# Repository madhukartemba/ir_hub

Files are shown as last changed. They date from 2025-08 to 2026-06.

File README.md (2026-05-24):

# IR Hub

A self-contained, open-source smart IR universal remote built around the ESP8266. IR Hub learns the codes from your existing TV/AC/audio remotes, stores them locally, and lets you fire them from a physical button, an on-device menu, Home Assistant (MQTT), or Alexa — all over your home Wi-Fi.

It ships as a complete hardware + firmware project: custom KiCad PCB, 3D-printed enclosure, and PlatformIO firmware with OTA updates.

- **Help (web preview):** https://ir-hub.pages.dev/help
- **Help (markdown source):** [`docs/HELP.md`](docs/HELP.md)
- **Release / OTA notes:** [`docs/RELEASE.md`](docs/RELEASE.md)

---

## What It Does

- **Learns IR remotes.** Point any IR remote at the receiver, press a button, and the Hub stores the raw signal.
- **Replays IR commands.** 8x parallel high-current IR LEDs give very long range so the Hub can sit across the room from the appliance.
- **Smart home bridge.** Each learned device shows up as an MQTT entity (works great with Home Assistant) and as an Alexa-controllable device (via Espalexa).
- **Standalone UI.** 128x64 OLED + single button + 30-LED NeoPixel ring + haptic motor + buzzer. No phone required for day-to-day use.
- **Captive-portal Wi-Fi setup.** First boot exposes an `IRHub V3 Setup` AP; users join it and configure Wi-Fi + MQTT from their phone.
- **OTA updates.** Cloud OTA (via Cloudflare Pages manifest, polled hourly) and LAN OTA (ArduinoOTA + mDNS auto-discovery).
- **Safe boot.** Boot-loop counter + LittleFS format-on-failure recovery so a bad save never bricks the device.

---

## Hardware Variants

**Only `v3` (the custom PCB build) is actively supported.** The older `v0` (NodeMCU perfboard) and `v1` (D1 Mini perfboard) variants still exist in the codebase as historical prototypes, but they are **deprecated** — no longer maintained, no longer released, and not recommended for new builds.

The rest of this README only covers v3.

---

## Bill of Materials (v3)

Full BOM with LCSC-style designators lives in [`PCB/IRHub_PCB_V3/production/bom.csv`](PCB/IRHub_PCB_V3/production/bom.csv). The major active parts:

| Block | Part | Role |
|---|---|---|
| MCU | **ESP-12F** (ESP8266) | Brains + Wi-Fi |
| USB | **USB-C receptacle + CH340C** | USB-UART for programming and 5 V power |
| Power | **AMS1117-3.3** LDO | 5 V -> 3.3 V regulation |
| Display | **OLED-128O064D** (SH1106, I²C) | 128x64 status/menu screen |
| LEDs | **30x WS2812B-2020** | Circular addressable RGB ring |
| IR TX | **8x IR204A** + UMH3N driver + AO3400A MOSFET | High-current IR blaster array |
| IR RX | **TSOP382xx** | 38 kHz IR demodulator for learning |
| Haptics | **DRV2605L** + external LRA (JST connector) | Tactile click feedback |
| Audio | **CMT-7525-80-SMT-TR** magnetic buzzer | UI beeps / chimes |
| Input | **Single tactile push button** | All UI navigation |

Plus passives, test points, and the JST-SH connector for the LRA.

---

## How To Build One (v3)

### 1. Order the PCB

KiCad project: [`PCB/IRHub_PCB_V3/`](PCB/IRHub_PCB_V3/)

- Source schematic + board: `IRHub_V3.kicad_sch`, `IRHub_V3.kicad_pcb`
- Manufacturing bundle: [`PCB/IRHub_PCB_V3/production/IR_Hub_3.zip`](PCB/IRHub_PCB_V3/production/IR_Hub_3.zip) (gerbers + drills, ready to upload to JLCPCB / PCBWay / OSHPark)
- For JLCPCB-style PCBA also use: `production/bom.csv` + `production/positions.csv`
- 3D preview / STEP: `IRHub_V3.step` and `IRHub_V3_Model.step`

Default board specs are 2-layer, 1.6 mm, HASL — anything in that ballpark from any low-cost fab works fine.

### 2. Print the Enclosure

3D-printable enclosure parts for the v3 PCB live in [`3D Print/Version 3/`](3D%20Print/Version%203/):

- `Base.stl` — main housing the PCB drops into
- `Top Cover.stl` — top shell with the OLED + button cutouts
- `Led Ring.stl` — diffuser ring that sits over the WS2812 ring

Plus the full Fusion 360 source as `IR Hub V3 v74.f3z`, and ready-to-print GCode under `3D Print/Version 3/GCode/`.

Recommended print settings: PLA, 0.2 mm layer height, 15–20% infill, supports off for `Top Cover` (geometry is overhang-friendly).

### 3. Assemble

1. Solder the PCB (or order PCBA). If hand-soldering, start with the QFP / SMD parts (CH340C, AMS1117, DRV2605L), then passives, then through-hole IR LEDs and the button, then the WS2812 ring last so it doesn't get cooked.
2. Verify 3.3 V on test point `TP9` and 5 V on `5V1` *before* installing the ESP-12F.
3. Solder/clip in the OLED, plug the LRA into the JST-SH connector.
4. Drop the populated PCB into the printed `Base`, screw on `Top Cover`, slip `Led Ring` over the LEDs.

### 4. Flash the Firmware

You only need to do this once — after that, OTA updates take over.

1. Install **PlatformIO** (VS Code extension or `pip install platformio`).
2. Clone this repo and open it in PlatformIO.
   ```bash
   git clone https://github.com/madhukartemba/ir_hub.git
   cd ir_hub
   ```
3. Create your `include/secrets.h` from the template:
   ```bash
   cp include/secrets.h.example include/secrets.h
   ```
   Edit it to set (all optional, but recommended):
   - `MQTT_HOST` / `MQTT_USER` / `MQTT_PASSWORD` — Home Assistant broker.
   - `OTA_PASSWORD` — required for LAN OTA pushes.
   - `OTA_MANIFEST_URL` — your Cloudflare Pages manifest URL (only needed if you fork and self-host releases).
4. Plug the assembled board into USB-C and run:
   ```bash
   pio run -e ir_hub_version_3 -t upload
   ```
5. Open the serial monitor to see boot logs:
   ```bash
   pio device monitor -b 115200
   ```

That's it — the rest of the configuration (Wi-Fi, MQTT credentials, learned remotes) happens on-device.

### 5. Power On & Configure

On first boot the Hub shows `IR Hub — Ready! (Offline)` and starts a captive-portal AP called **`IRHub V3 Setup`**. Connect a phone to it and the captive portal walks you through Wi-Fi (and optional MQTT) setup. From there, see the [User Help Guide](docs/HELP.md) for adding remotes, using Alexa, etc.

---

## Pinout (v3)

For reference, defined in [`src/config.h`](src/config.h):

| Function | ESP-12F Pin |
|---|---|
| Button | D0 |
| OLED SCL | D1 |
| OLED SDA | D2 |
| Buzzer | D3 |
| IR Receiver | D5 |
| IR Transmitter | D6 |
| NeoPixel ring | D7 |

---

## Project Layout

```
ir_hub/
  src/                Firmware entry + UI screens
  lib/                Internal libraries (IR, MQTT, Display, OtaUpdater, etc.)
  include/            Project headers + secrets template
  PCB/                KiCad sources + gerbers + production BOM (v3; v1 archived)
  3D Print/           Fusion sources + STL + GCode for enclosures
  docs/               User help, release/OTA documentation
  scripts/            Release automation + local OTA upload helper
  ota/                Public OTA manifest served via Cloudflare Pages
  binaries/           Signed firmware images served via Cloudflare Pages
```

---

## For Developers

All commands target v3 — the older `v0` / `v1` PlatformIO envs are deprecated and not part of the release pipeline.

- **Build:** `pio run -e ir_hub_version_3`
- **Cut a release:** `python3 scripts/release.py 1.2.3` — bumps `custom_firmware_version`, builds `ir_hub_version_3`, stages the binary under `binaries/`, updates `ota/manifest.json`, commits + pushes. See [`docs/RELEASE.md`](docs/RELEASE.md) for the full flow.
- **LAN OTA push:** `python3 scripts/local_upload_ota.py -e ir_hub_version_3 --discover` — mDNS-discovers `ir-hub-*` devices and pushes the current build over the network. Password is read from `include/secrets.h`.

---

## License

MIT — see `LICENSE` (or use the source freely; attribution appreciated).

---

<div align="center">
  Made by <a href="mailto:madhusmiles.madhukar@gmail.com">Madhukar Temba</a>
</div>

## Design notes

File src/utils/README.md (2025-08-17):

# Utils Directory

This directory contains utility classes and functions that can be reused across different parts of the application.

## MenuUtils

The `MenuUtils` class provides a reusable scrollable menu implementation that can be used across different screens in the application.

### Features

- **Scrollable Menus**: Automatically handles scrolling when there are more menu items than can fit on screen
- **Multiple Input Types**: Supports different input formats (vector of strings, array of const char\*, etc.)
- **Consistent UI**: Provides a consistent look and feel across all menus
- **Easy Integration**: Simple to integrate into existing screens

### Usage

```cpp
#include "../utils/MenuUtils.h"

// For const char* arrays
const char* menuItems[] = {"Option 1", "Option 2", "Option 3", "Back"};
MenuUtils::drawScrollableMenu(menuItems, 4, selectedIndex, 3, 20);

// For vector of strings
std::vector<std::string> items = {"Option 1", "Option 2", "Option 3"};
MenuUtils::drawScrollableMenu(items, selectedIndex, 3, 20);
```

### Parameters

- `items`: Array or vector of menu items
- `selectedIndex`: Currently selected item index
- `maxVisibleItems`: Maximum number of items to show at once (default: 3)
- `startY`: Y-coordinate to start drawing the menu (default: 20)

### Integration

To use this utility in a new screen:

1. Include the header: `#include "../utils/MenuUtils.h"`
2. Add a `selectedIndex` member variable to track selection
3. Update the button click handler to increment `selectedIndex`
4. Replace manual menu drawing with `MenuUtils::drawScrollableMenu()`

### Examples

See the following files for examples of how to use MenuUtils:

- `src/ui/settings/Settings.h`
- `src/ui/devices/Devices.h`
- `src/ui/devices/DeviceActions.h`
- `src/ui/MainMenu.h`

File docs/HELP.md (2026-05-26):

# IR Hub — User Guide

Welcome to your IR Hub! This guide walks you through everything you need — setting it up, using it daily, and getting the most out of its smart-home features.

> Looking for something specific? Jump straight to the section you need below.

## Quick Navigation

- [What is IR Hub?](#what-is-ir-hub)
- [Button Cheat Sheet](#button-cheat-sheet)
- [LED Ring Colors](#led-ring-colors)
- [First-Time Setup](#first-time-setup)
- [Adding a Remote (Add Device)](#adding-a-remote-add-device)
- [Using Your Saved Devices](#using-your-saved-devices)
- [Smart Home Integration](#smart-home-integration)
- [Settings Menu](#settings-menu)
- [Keeping It Up to Date](#keeping-it-up-to-date)
- [Upgrading to 2.0.0](#upgrading-to-200)
- [Resetting Your Hub](#resetting-your-hub)
- [Troubleshooting](#troubleshooting)
- [Contact & Support](#contact--support)

---

## What is IR Hub?

IR Hub is a smart infrared (IR) remote that lives in one place in your home and replaces a drawer full of remotes. It can:

- **Learn** the button presses from any IR remote you already own (TV, AC, set-top box, fan, soundbar — anything that uses an IR remote).
- **Replay** those signals on command, with enough range to reach across the room.
- **Connect to your smart home** so you can also trigger your appliances from Home Assistant or Alexa.

Once set up, you can keep using your old remotes *and* control everything from your phone, your voice, or the Hub itself.

---

## Button Cheat Sheet

Everything on IR Hub is done with one button. Here's the full list of gestures:

| Where you are | Single Click | Long Press |
|---|---|---|
| Home screen (display sleeping) | Wake the screen | Wake the screen |
| Home screen (display awake) | (nothing) | Open the **Main Menu** |
| Inside a menu | Move to the **next item** | **Select** the highlighted item |
| Inside a confirmation screen | Cancel / go back | **Confirm** the action |

*Tip: If the screen is dark, just click once — that always wakes it up.*

---

## LED Ring Colors

The ring of lights around the Hub gives you quick visual feedback:

| Color | What it means |
|---|---|
| Soft white / breathing | Idle, ready to use |
| Green pulse | Sent a successful "ON" command |
| Orange / red pulse | Sent an "OFF" command |
| Rainbow sweep | Successfully added a new device |
| Solid green | Everything is connected and ready |
| Solid red | Something went wrong (check the screen for details) |
| Blue breathing | Currently looking at info screens or Help / Contact |

The ring will fade out after a few seconds of inactivity to save power — that's normal.

---

## First-Time Setup

When you first power your Hub on, here's what to expect:

1. **Plug it in.** The screen will say `IR Hub — Initializing...`, then the ring will light up.
2. **Connect to the setup network.** Take your phone and look for a Wi-Fi network named **`IRHub V3 Setup`**. Join it.
3. **Open the setup page.** Your phone may open the setup page automatically. If it doesn't, open **`http://192.168.4.1`** in your browser.
4. **Pick your Wi-Fi.** Choose your home Wi-Fi network from the list and enter the password.
5. *(Optional)* **Enter your MQTT details** if you want to connect to Home Assistant — see [Smart Home Integration](#smart-home-integration) below.
6. **Done!** The Hub will reboot, connect to your network, and show `Ready!` on the screen.

You can now start adding your remotes.

---

## Adding a Remote (Add Device)

Let's teach the Hub how to control one of your appliances.

1. From the Home screen, **long-press** the button to open the **Main Menu**.
2. Click to highlight **Add Device**, then long-press to select.
3. Grab the original remote for the appliance you want to control (e.g. your TV remote).
4. **Point the remote at the front of the Hub** (the small dark window is the IR receiver) from about 10–30 cm away.
5. When prompted, press the **ON** button on your remote.
6. When prompted again, press the **OFF** button (or repeat the same button if the appliance uses a single toggle).
7. The Hub will confirm with a rainbow sweep and a happy chime — your new device is saved!

**Recording tips:**
- Press firmly but briefly — a quick, deliberate press works better than holding it down.
- Make sure you have line-of-sight between your remote and the Hub.
- If recording fails, try again from a slightly closer distance.
- Avoid direct sunlight or bright halogen lights pointed at the Hub — they create IR noise.

---

## Using Your Saved Devices

Once you've added a device, you have three ways to control it:

**1. From the Hub itself**
- Open **Main Menu -> Devices**
- Pick the appliance and toggle it on/off

**2. From your phone / Home Assistant** (if MQTT is set up)
- Each device appears automatically as a switch in Home Assistant
- Trigger it from dashboards, automations, scripts, etc.

**3. With your voice** (Alexa, via local discovery)
- Say *"Alexa, discover devices"* once after adding a new appliance on the Hub
- Then use the name Alexa shows (you can rename it in the Alexa app for easier voice commands)
- The Hub supports up to **20** saved devices

---

## Smart Home Integration

### Home Assistant (MQTT)

If you have a Home Assistant install with an MQTT broker (e.g. Mosquitto), the Hub can connect to it automatically:

- During first-time setup, enter your **MQTT broker address**, **username**, and **password** in the captive portal.
- Each device you add later will publish itself on MQTT automatically — no Home Assistant config edits required.
- You can check the connection status at any time under **Settings -> MQTT status**.

### Alexa

The Hub exposes each saved device to Alexa over your local Wi-Fi (no Alexa skill or cloud account linking required):

1. Make sure your Echo and the Hub are on the **same Wi-Fi network** (same band — many routers split 2.4 GHz and 5 GHz).
2. Add at least one device on the Hub.
3. Say *"Alexa, discover devices"* — each appliance should appear as its own entry.
4. Control it by name, e.g. *"Alexa, turn on Living Room TV."*

**Names in the Alexa app**

When Alexa first discovers a device, it may show a short hex prefix before the name you set on the Hub (for example `46ef8b TV 1`). That prefix keeps each device separate in Alexa's list. **Rename the device inside the Alexa app** to whatever you want for voice control (e.g. `Living Room TV`). The rename stays in Alexa only — the name on the Hub screen does not change.

**After you add or remove a device on the Hub**

Say *"Alexa, discover devices"* again so Alexa picks up the latest list.

**Turning Alexa off**

Open **Settings -> Alexa: On**, then long-press and confirm on the **Disable Alexa?** screen. Discovery and voice control stop immediately until you turn Alexa back on from Settings (no confirmation required to re-enable).

---

## Settings Menu

From the Main Menu, open **Settings** to access:

| Setting | What it does |
|---|---|
| **Sound** | Turns the buzzer beeps on/off |
| **Alexa** | Turns local Alexa discovery and control on/off (disabling asks for confirmation) |
| **Haptics** | Turns the vibration feedback on/off *(shown only if your Hub has a haptics driver)* |
| **Check for Updates** | Manually look for new firmware |
| **Firmware** | Shows the version you're currently running |
| **Last check** | When the Hub last looked for an update |
| **Update status** | The result of the last update check |
| **MQTT status** | Whether the Hub is connected to your MQTT broker |
| **Restart** | Safely reboot the Hub |
| **Reset Wi-Fi** | Forget your saved Wi-Fi (for moving to a new network) |
| **Erase Saved Data** | Delete all saved remotes/devices |
| **Factory Reset** | Wipe **everything** and start over |

Disabling Alexa, and all destructive actions (reset / erase / factory reset), ask for a long-press confirmation on a dedicated screen so you won't accidentally change them.

---

## Keeping It Up to Date

Your Hub gets better over time as new features are released. Updates are delivered automatically over the internet — you don't need to do anything.

**Automatic updates**
- The Hub checks for a new version once per hour while it's online.
- If one is found, it downloads and installs it on its own. The screen will say `Update found` and `Restarting to install...`, then come back online a minute later running the new version.

**Manual updates**
- Open **Settings -> Check for Updates** any time.
- A dedicated screen will show you exactly what's happening:
  - `Checking...` — looking for a new version
  - `Up to date` — you're already on the latest
  - `Update found` — installing now
  - `No Wi-Fi` — Hub isn't connected, see [Troubleshooting](#troubleshooting)
  - `Low heap` — try again in a few seconds, the Hub was busy
  - `Check failed` — temporary network blip, just try again

Most routine updates keep your saved remotes, Wi-Fi, MQTT settings, and preferences (sound, haptics, Alexa on/off).

**Major upgrades (such as 2.0.0)** can change how devices appear in Alexa or Home Assistant even when your remotes are still on the Hub. See [Upgrading to 2.0.0](#upgrading-to-200) below.

---

## Upgrading to 2.0.0

Firmware **2.0.0** is a major release. After your Hub installs it (automatically or via **Settings -> Check for Updates**), you may need a few extra steps so smart-home integrations match the new device identities.

**What usually stays the same**

- Wi-Fi credentials
- Sound, haptics, and Alexa on/off preferences
- Devices you already taught the Hub *(if they were saved with the current storage format)*

**Alexa (recommended after updating)**

1. In the **Alexa app**, delete every old IR Hub / Hue-style device that no longer works or shows the wrong name.
2. Say *"Alexa, discover devices"* again.
3. Rename each device in the Alexa app if you see a hex prefix (e.g. change `46ef8b TV 1` to `Living Room TV`).

Stale entries from older firmware often cause "only one device," wrong names, or controls that trigger the wrong appliance until you delete and rediscover.

**Home Assistant (MQTT)**

- New devices you add after the update publish with the current identity automatically.
- Old switch entities may show as unavailable or duplicate. Remove stale `switch.ir_hub_…` entities in Home Assistant (or restart MQTT discovery) and use the freshly published ones.

**If a saved remote disappeared from the Hub menu**

Very old device files from before the Hub used permanent UUIDs are skipped at boot. **Re-add** that appliance via **Add Device** — you do not need a factory reset unless you want a completely clean slate.

---

## Resetting Your Hub

There are three levels of reset, depending on what you want to clear:

| Action | What it clears | What it keeps |
|---|---|---|
| **Restart** | Nothing — just a fresh boot | Everything |
| **Reset Wi-Fi** | Wi-Fi network + password | Saved remotes, MQTT, sound/haptic settings |
| **Erase Saved Data** | All learned remotes/devices | Wi-Fi, MQTT, sound/haptic settings |
| **Factory Reset** | **Everything** (Wi-Fi, devices, settings) | Nothing |

All of these are under **Settings**. Each one shows a confirmation screen — **long-press** to actually go through with it.

After a **Factory Reset**, the Hub starts fresh, gets a **new Alexa bridge identity**, and reopens the `IRHub V3 Setup` Wi-Fi network, ready for [First-Time Setup](#first-time-setup) again. That is the cleanest way to clear confused Alexa caches — delete any leftover IR Hub devices in the Alexa app, then discover again after setup.

---

## Troubleshooting

### The screen is blank
The Hub dims the screen after a few seconds of inactivity to save power. **Click the button once** to wake it up.

### Can't find the `IRHub V3 Setup` Wi-Fi
- Wait about 30 seconds after plugging it in — the network takes a moment to start.
- Make sure your phone's Wi-Fi is on and refresh the list.
- If you've already set it up before, it won't broadcast `IRHub V3 Setup` again. Use **Settings -> Reset Wi-Fi** to get back to setup mode.

### Captive portal doesn't open on my phone
- Open **`http://192.168.4.1`** directly in your browser.
- Some Android phones need you to tap the network and choose *"Sign in to Wi-Fi network"*.

### My appliance doesn't respond after I added it
- Make sure the Hub has line-of-sight to your appliance.
- Try re-adding it; sometimes the first recording captures a weak signal.
- IR has a typical range of about 5–7 meters indoors — closer is more reliable.

### Update check says `No Wi-Fi`
- The Hub is offline. Check your home Wi-Fi is up.
- If you've changed your router/password recently, go to **Settings -> Reset Wi-Fi** and reconnect.

### Update check says `Check failed` or `Low heap`
- Usually a temporary network blip or a busy moment. Wait a few seconds and try again.
- If it keeps failing, use **Settings -> Restart** and then try one more time.

### MQTT status shows `Disconnected`
- Verify your broker's address, port, username, and password are correct.
- Make sure your broker is reachable from the same Wi-Fi the Hub is on.
- Try **Settings -> Restart** to force a fresh connection attempt.

### Alexa can't find my devices
- Make sure your Echo and the Hub are on the **same Wi-Fi network** (and the same Wi-Fi band — some routers separate 2.4 GHz and 5 GHz).
- Check **Settings** — **Alexa** must be **On**. If you disabled it earlier, long-press to turn it back on.
- Say *"Alexa, discover devices"* after adding new ones on the Hub.
- Wait up to a minute after the Hub boots — it advertises itself periodically on the network.

### Alexa shows only one device, or the wrong device opens when I tap it
- This usually means Alexa is still using **cached entries from older firmware**. In the Alexa app, **delete all** IR Hub / related smart-home devices tied to this Hub, then say *"Alexa, discover devices"* once.
- After discovery, each entry should be separate. Rename them in the Alexa app if you see a hex prefix in the name.

### Alexa name looks like `a1b2c3 TV 1` — can I change it?
- Yes. **Rename in the Alexa app** for voice commands. The name on the Hub's own screen stays whatever you set when you added the device.

### I don't want Alexa on this Hub at all
- **Settings -> Alexa: On** → long-press → confirm **Disable Alexa?**. The Hub stops all Alexa discovery and control until you enable it again.

### Nothing is working — I just want to start over
Use **Settings -> Factory Reset**. This clears everything and brings you back to the first-time setup flow.

---

## Contact & Support

Need a hand? We're happy to help.

- **On the device:** Open **Main Menu -> Contact** and scan the QR code with your phone — it opens an email to support directly.
- **Help docs anywhere:** Scan the **Help** QR (Main Menu -> Help) to open this guide on your phone.
- **Email:** [madhusmiles.madhukar@gmail.com](mailto:madhusmiles.madhukar@gmail.com)

---

<div align="center">
  Made with care by Madhukar Temba — enjoy your IR Hub!
</div>

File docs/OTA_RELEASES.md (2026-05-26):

# Remote OTA via GitHub Releases

The device polls a JSON manifest in this repo every 1 hour (and once shortly
after boot). When the manifest version is newer than what the device is
running, it downloads `firmware_<variant>_v<version>.bin` via jsDelivr
(serving the file from this repo's `binaries/` folder) and self-flashes.
No physical access required.

The binary is *also* attached to a GitHub Release for human visibility, but
the device deliberately does not download from there — see the TLS note
below.

## One-time setup

### 1. Configure the device

Edit `include/secrets.h` before flashing:

```c
#define OTA_PASSWORD       "pick-something-long"
#define OTA_MANIFEST_URL   "https://<your-project>.pages.dev/ota/manifest.json"
```

- `OTA_PASSWORD` protects LAN pushes via `pio run --target upload --upload-port <ip>`.
  An empty string disables the check (logged as a warning at boot).
- `OTA_MANIFEST_URL` is what the device polls. Empty disables HTTP-pull OTA
  entirely.

**Use Cloudflare Pages for both manifest and binary, not jsDelivr, `raw.githubusercontent.com`
or GitHub Releases.** Cloudflare Pages is a free hosting service that you can link to your GitHub repo, 
and — crucially — supports the TLS MFLN extension (RFC 6066). The ESP8266
has only ~18-20 KB free heap available for a TLS handshake, which is too
tight to receive full-size 16 KB TLS records. MFLN lets the client negotiate
smaller records so a 4 KB receive buffer is sufficient.

Fastly (`raw.githubusercontent.com`), jsDelivr (which uses Fastly for some requests), and the GitHub Releases edge
(`objects.githubusercontent.com`) all negotiate MFLN inconsistently. They
work from a laptop but crash the ESP8266 mid-handshake or mid-download with
`Unhandled C++ exception: OOM` or TLS aborts.

That's why every release commits the firmware binary into this repo's
`binaries/` folder (e.g. `binaries/firmware_v3_v1.0.3.bin`) and the
manifest URL points at Cloudflare Pages:

```
https://<your-project>.pages.dev/binaries/firmware_v3_v1.0.3.bin
```

The GitHub Release still gets the binary as an attached asset for easy
manual download, but the device never touches that URL.

### 2. Commit the manifest skeleton

Create `ota/manifest.json` in this repo:

```json
{
  "variants": {
    "v0": { "version": "0.0.0", "url": "" },
    "v1": { "version": "0.0.0", "url": "" },
    "v3": { "version": "1.0.0", "url": "https://<your-project>.pages.dev/binaries/firmware_v3_v1.0.0.bin" }
  }
}
```

Only the variant that matches the device's `OTA_HW_VARIANT` (set per env in
`platformio.ini`) is consulted, so the others can stay at `0.0.0` until you
have a build for them.

### 3. Flash version 1.0.0 to the device

```bash
pio run -e ir_hub_version_3 --target upload
```

The Home screen header will now read `IR Hub v1.0.0`.

## Cutting a new release

Use `scripts/release.py` — it does all of the below in one command. See
`docs/RELEASE.md`. If you want to do it manually:

1. **Bump the version** in `platformio.ini`:

   ```ini
   [env]
   custom_firmware_version = 1.0.1
   ```

2. **Build the binary**:

   ```bash
   pio run -e ir_hub_version_3
   ```

3. **Commit the binary into `binaries/`** so Cloudflare Pages can serve it:

   ```bash
   mkdir -p binaries
   cp .pio/build/ir_hub_version_3/firmware.bin binaries/firmware_v3_v1.0.1.bin
   ```

4. **(Optional) Create a GitHub Release** named `v1.0.1` for human visibility:

   ```bash
   gh release create v1.0.1 binaries/firmware_v3_v1.0.1.bin \
     --title "v1.0.1" \
     --notes "Fix XYZ, improve ABC"
   ```

5. **Update `ota/manifest.json`** to point at the Cloudflare Pages URL:

   ```json
   {
     "variants": {
       "v3": {
         "version": "1.0.1",
         "url": "https://<your-project>.pages.dev/binaries/firmware_v3_v1.0.1.bin"
       }
     }
   }
   ```

6. **Commit and push** `platformio.ini`, `binaries/`, and `ota/manifest.json`
   to `main`. The device will pick it up on its next poll.

7. **(Optional) Trigger an immediate update** instead of waiting up to an hour.
   If the device has MQTT configured, publish an empty message to its OTA
   topic:

   ```bash
   mosquitto_pub -h <broker> -u <user> -P <pass> \
     -t "ir_hub/<mac>/ota/check" -n
   ```

   The MAC appears in the device's MQTT discovery topics (and in the boot log).

## What the device does

On boot:
1. Bring up Wi-Fi, MQTT, Alexa, etc.
2. Wait 30 seconds (lets transient heap settle).
3. GET the manifest.
4. If a newer version exists, shut down MQTT to free heap, run
   `ESP8266HTTPUpdate.update(url)`, show progress on OLED + LED ring,
   restart on success. Failures get logged and shown briefly, then the
   device keeps running the old firmware.

On the loop, every 1 hour: same as steps 3-4 above.

Whenever a manifest fetch fails or the update aborts mid-stream, the existing
`BootGuard` + `LittleFS` recovery handles the worst case. If the new firmware
crashes 3 times in a row at boot, the device sticks on the error screen
("Boot loop detected — Power off & re-flash") instead of endlessly cycling.

## Security notes

The default config uses `WiFiClientSecure::setInsecure()` — bytes are
encrypted in transit but the server cert is not validated. That's good enough
to stop casual snooping but won't stop an attacker who can MITM the
connection to your repo (very rare in practice, especially against GitHub).

If you need stronger guarantees:

- **Pin a fingerprint.** Read GitHub's TLS cert SHA-256 once, hard-code it
  via `secure->setFingerprint(...)`. Breaks on cert rotation (~12 months).
- **Sign the binary.** Espressif supports SHA-256 signature verification in
  the bootloader (`USE_SIGNED_OTA`). Slightly more involved but the gold
  standard for fleet OTA.

For a friend-tester rollout, `setInsecure()` over HTTPS to a release URL
under your GitHub account is generally fine.

## Disabling OTA

If you ever want to ship a device without remote updates (e.g. air-gapped
network):

```c
#define OTA_MANIFEST_URL ""
```

The OTA module logs `[OTA-HTTP] Disabled` at boot and never touches the
network.

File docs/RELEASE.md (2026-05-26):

# Releasing a new firmware version

`scripts/release.py` is the single command that ships an OTA-deliverable
firmware. It bumps the version, builds the binaries, drops a versioned
copy under `binaries/` (which is what the device actually downloads via
Cloudflare Pages), updates `ota/manifest.json`, and commits + pushes in
the right order so that no device can ever see a manifest pointing at a
binary that doesn't exist yet. GitHub Releases are optional and opt-in.

For the underlying OTA mechanism (manifest schema, security model, what the
device does on the wire), see [`OTA_RELEASES.md`](OTA_RELEASES.md). This
file is the day-to-day operator's guide.

## Prerequisites

One-time setup on your machine:

```bash
pio --version            # PlatformIO CLI
gh --version             # GitHub CLI
gh auth login            # authenticate gh against github.com
```

The script will refuse to run if any of `pio` or `git` is missing.
If you pass `--github-release`, it will also require `gh` and authenticated
GitHub CLI access.

You also need:

- A clean git working tree (only `platformio.ini` and `ota/manifest.json` are
  allowed to be dirty, since the script is about to overwrite them anyway).
- The branch you want to release from checked out — usually `main`.
- `OTA_MANIFEST_URL` set in `include/secrets.h` on the devices you've already
  flashed, pointing at the manifest in *this* repo. See `OTA_RELEASES.md`
  for the one-time device setup.

## Quick start

Cut a release with automatic patch bump (uses `platformio.ini`'s current
`custom_firmware_version`, increments patch by 1):

```bash
scripts/release.py --notes "Fix touch-button EMI during recording"
```

Cut a v3-only release with manual notes:

```bash
scripts/release.py 1.0.1 --notes "Fix touch-button EMI during recording"
```

Cut a release for every PCB variant in one go:

```bash
scripts/release.py 1.0.1 \
    --envs ir_hub_version_0 ir_hub_version_1 ir_hub_version_3 \
    --notes "Bring all variants to parity"
```

Let GitHub generate notes from your commits since the last tag:

```bash
scripts/release.py 1.0.1 --github-release --auto-notes
```

Inspect what would happen, without doing anything:

```bash
scripts/release.py 1.0.1 --dry-run
```

## All flags

| Flag | Purpose |
| --- | --- |
| `version` (positional, optional) | New semver, e.g. `1.0.1` or `1.0.1-rc1` (no leading `v`). If omitted, script auto-bumps patch from `platformio.ini` (for example `1.0.13 -> 1.0.14`). |
| `--envs` | PlatformIO envs to build. Default: `ir_hub_version_3`. |
| `--notes` | Release notes as a string. Mutually exclusive with `--notes-file`. |
| `--notes-file PATH` | Read release notes from a markdown file. |
| `--auto-notes` | Let `gh` generate notes from commits since the last tag. |
| `--github-release` | Also create/update a GitHub Release with uploaded binary assets (optional). |
| `--draft` | Create the GitHub Release as a draft (publish manually). |
| `--repo OWNER/REPO` | Override the auto-detected GitHub slug. |
| `--no-push` | Commit locally but don't push (useful for reviewing the commit first). |
| `--no-commit` | Skip the git add/commit/push entirely (the manifest still gets rewritten on disk). |
| `--no-release` | Deprecated alias; keeps GitHub Release creation disabled. |
| `--dry-run` | Print every action it would take, then exit. |

## What it does, step by step

1. **Preflight checks**
   - `pio`, `gh`, `git` are on PATH.
   - `gh auth status` returns success.
   - Working tree is clean (excluding the two files about to be rewritten).
   - The `vX.Y.Z` tag doesn't exist yet locally.
2. **Resolves release version**:
   - Uses the provided positional `version` when passed, or
   - auto-bumps patch from `platformio.ini`'s `custom_firmware_version`
     when omitted.
   Then **bumps `custom_firmware_version`** in `platformio.ini` so the next
   build compiles in the new `FIRMWARE_VERSION` macro.
3. **Builds** each env in `--envs` via `pio run -e <env>`.
4. **Stages binaries** in two places:
   - `release/firmware_<variant>.bin` — gitignored, used only as the asset
     uploaded to the GitHub Release for human visibility.
   - `binaries/firmware_<variant>_v<version>.bin` — committed to git. This
     is the file the device actually downloads, via jsDelivr's CDN.
   The variant is derived from the env name (`ir_hub_version_3` → `v3`) so
   it matches the device's `OTA_HW_VARIANT`.
5. **(Optional) Creates the GitHub Release** (only when `--github-release`
   is set) with `gh release create vX.Y.Z firmware_*.bin --title vX.Y.Z`.
   If the tag already exists from a partial previous run, falls back to
   `gh release upload --clobber` so re-runs are idempotent.
6. **Updates `ota/manifest.json`** with the new version and per-variant URLs
   pointing at jsDelivr:

   ```json
   {
     "variants": {
       "v3": {
         "version": "1.0.1",
         "url": "https://cdn.jsdelivr.net/gh/<you>/<repo>@main/binaries/firmware_v3_v1.0.1.bin"
       }
     }
   }
   ```

   Repo slug auto-detected from `git remote origin`. Existing variants you
   didn't build are left untouched.
7. **Commits and pushes** `platformio.ini` + `ota/manifest.json` +
   `binaries/firmware_<variant>_v<version>.bin` with the message
   `chore(release): vX.Y.Z`.
8. **No manual CDN purge needed**. Cloudflare Pages deploys fresh content
   for the new commit; the binary path is versioned (`..._vX.Y.Z.bin`)
   so each release is a unique URL.

If `--github-release` is used, the release goes live in step 5 *before*
the manifest is published in step 7 — a device polling between those two
steps either sees the old manifest (and does nothing) or sees the new
manifest (and the binary URL already works). It can never see
"new manifest -> 404 binary".

## After running

Devices check the manifest 30 s after boot and then every 1 hour, so a
release rolls out within an hour organically. To trigger an immediate
pickup, publish an empty MQTT message to the device's OTA topic:

```bash
mosquitto_pub -h <broker> -u <user> -P <pass> \
    -t "ir_hub/<mac>/ota/check" -n
```

The MAC is the lowercase, no-separator hex shown in the device's MQTT
discovery topics (and printed in the boot log).

## Recovering from a partial release

The script is designed to be re-run safely. Common scenarios:

- **`pio run` failed mid-build.** Fix the code, commit, re-run the script.
  The version bump already in `platformio.ini` is fine — the script will
  detect it and continue.
- **Build succeeded, `gh release create` failed (e.g. network).** Re-run the
  script with the same version. It detects the existing tag and uses
  `gh release upload --clobber` to push the binaries to the already-created
  release.
- **Release uploaded but `git push` failed.** Push manually:
  `git push`. Devices will pick up the manifest as soon as jsDelivr's edge
  has it (purge with
  `curl https://purge.jsdelivr.net/gh/<you>/<repo>@main/ota/manifest.json`
  if you don't want to wait the default ~12 h TTL).

If you need to abandon a release entirely:

```bash
gh release delete vX.Y.Z --yes        # remove the GitHub release
git tag -d vX.Y.Z                     # remove local tag
git push --delete origin vX.Y.Z       # remove remote tag (only if pushed)
git revert HEAD                       # back out the manifest bump
```

## Troubleshooting

**"working tree has uncommitted changes"** — Stash or commit your local edits
first. The script intentionally won't proceed with random work-in-progress
files staged for a release.

**"git tag vX.Y.Z already exists locally"** — You've already run a release
for this version. Either pick a new version (recommended) or delete the
old tag (`git tag -d vX.Y.Z`) if you really want to overwrite.

**"cannot auto-bump ... pre-release/non-semver"** — Auto-bump only works for
stable semver in `platformio.ini` (`X.Y.Z`). If current value is something
like `1.0.1-rc1` (or non-semver), pass an explicit positional version.

**`gh auth status` failed** — Run `gh auth login` and follow the prompts.

**Device never picks up the new release** — Check:

1. `OTA_MANIFEST_URL` is set in the device's `secrets.h` and the device was
   flashed *with* that URL baked in.
2. The device has Wi-Fi.
3. The manifest URL returns 200 in your browser.
4. `FIRMWARE_VERSION` on the device's home screen is older than the
   manifest's version (the device only updates when the manifest version is
   strictly newer).
5. The device's free heap is above ~18 KB at check time (look for
   `[OTA-HTTP] Skipping check, low heap` in the serial log).

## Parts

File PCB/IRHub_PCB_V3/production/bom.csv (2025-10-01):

Designator | Footprint | Quantity | Value | LCSC Part #
5V1 | TestPoint_Pad_D1.0mm | 1 | VCC
AMS1117 | SOT-223-3_TabPin2 | 1 | AMS1117-3.3
BZR1 | XDCR_CMT-7525-80-SMT-TR | 1 | CMT-7525
C1, C2, C5, C6, C7 | 0805 | 5 | 1µF
C10 | 0805 | 1 | 2µF
C11, C8 | 0805 | 2 | 10µF
C3, C4 | 1206 | 2 | 10µF
C9 | 0805 | 1 | 0.1µF
CH340C1 | SOIC-16_3.9x9.9mm_P1.27mm | 1 | CH340C
D1, D10, D11, D12, D13, D14, D15, D16, D17, D18, D19, D2, D20, D21, D22, D23, D24, D25, D26, D27, D28, D29, D3, D30, D4, D5, D6, D7, D8, D9 | LED_WS2812B-2020_PLCC4_2.0x2.0mm | 30 | WS2812B-2020
DISPTOUCH1 | JST_SH_BM06B-SRSS-TB_1x06-1MP_P1.00mm_Vertical | 1 | DispTouch
DS1 | OLED-128O064D | 1 | OLED-128O064D
ESP1 | ESP-12E | 1 | ESP-12F
IR_L1, IR_L2, IR_L3, IR_L4, IR_L5, IR_L6, IR_L7, IR_L8 | LED_D3.0mm_IRBlack | 8 | IR204A
IR_RECV1 | Vishay_MINICAST-3Pin | 1 | TSOP382xx
LRA1 | PinHeader_1x02_P2.00mm_Vertical | 1 | Conn_01x02_Socket
MFT1, MFT2 | SOT-23 | 2 | AO3400A
Q1 | SOT-363_SC-70-6 | 1 | UMH3N
R1, R2 | 1206 | 2 | 470
R10, R11, R12, R13, R14, R7, R8, R9 | 1210 | 8 | 43
R15, R5 | 1206 | 2 | 68
R16, R17, R18, R21, R6 | 1206 | 5 | 12000
R19, R20 | 0805 | 2 | 2200
R22, R23, R25 | 0805 | 3 | 10000
R24 | 0805 | 1 | 390000
R3, R4 | 1206 | 2 | 5100
SW1 | SW_SPST_TS-1088-xR020 | 1 | SW_Push
TP9 | TestPoint_Pad_D1.0mm | 1 | 3V3
T_D+1 | TestPoint_Pad_D1.0mm | 1 | D+
T_D-1 | TestPoint_Pad_D1.0mm | 1 | D-
T_D6 | TestPoint_Pad_D1.0mm | 1 | D6
T_D7 | TestPoint_Pad_D1.0mm | 1 | D7
T_GND1 | TestPoint_Pad_D1.0mm | 1 | GND
T_RX1 | TestPoint_Pad_D1.0mm | 1 | RX
T_TX1 | TestPoint_Pad_D1.0mm | 1 | TX
U1 | VSSOP-10_3x3mm_P0.5mm | 1 | DRV2605LDGS
USB1 | USB_C_Receptacle_GCT_USB4110 | 1 | USB_C_Receptacle_USB2.0_16P

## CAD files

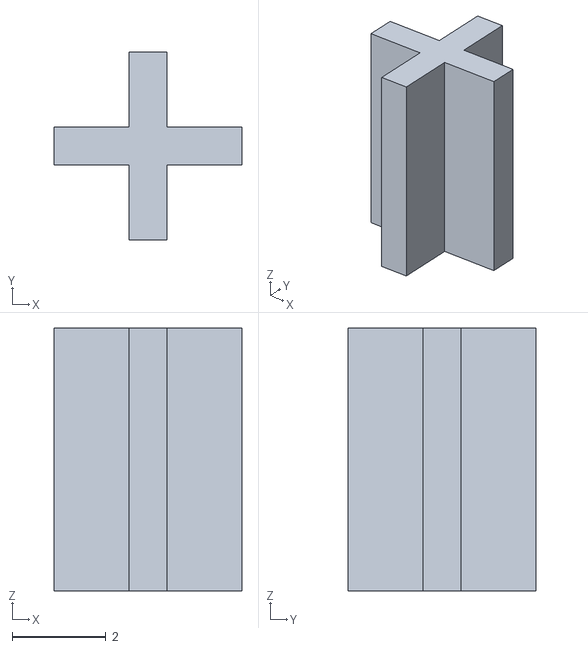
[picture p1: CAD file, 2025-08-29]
3D Print/PCB_Version/LedSupport Version 5.stl
4.00 x 4.00 x 5.60

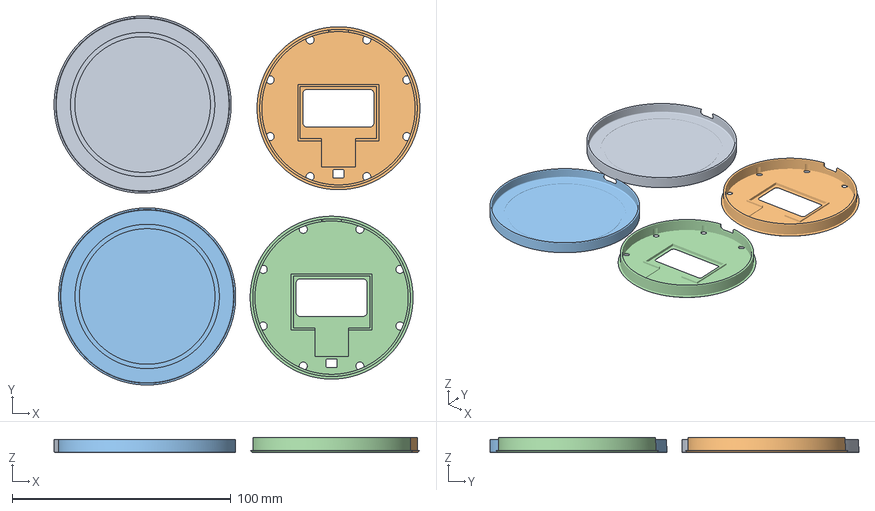
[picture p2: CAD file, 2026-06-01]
3D Print/Version 3/CE3E3V2_Set.3mf
167.3 x 168.7 x 7.00 mm
Base.stl
Top Cover.stl
Base.stl(1)
Top Cover.stl(1)

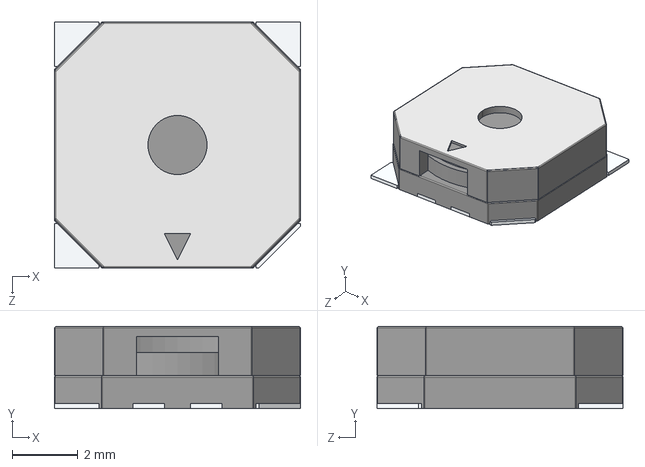
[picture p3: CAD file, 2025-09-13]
PCB/IRHub_PCB_V3/CMT-7525-80-SMT-TR/CMT-7525-80-SMT-TR.step
7.50 x 2.50 x 7.50 mm

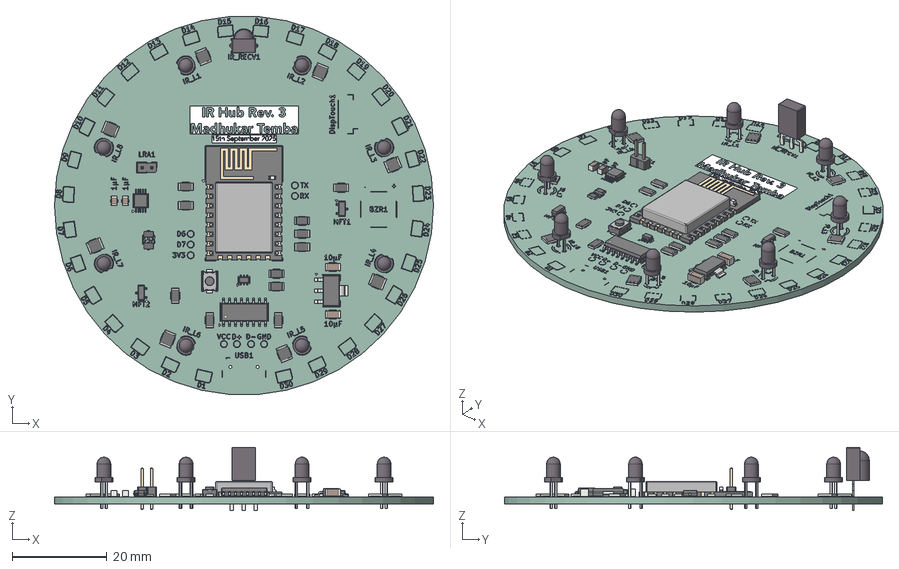
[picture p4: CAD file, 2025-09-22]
PCB/IRHub_PCB_V3/IRHub_V3.step
80.0 x 79.8 x 13.3 mm
R_1210_3225Metric x 8
LED_D3.0mm_IRBlack x 8
C_1206_3216Metric x 2
R_1206_3216Metric x 11
SOT-223
R_0805_2012Metric x 2
ESP-12E
Vishay_MINICAST-3Pin
SOT-363_SC-70-6
SOT-23 x 2
SW_SPST_TS-1088-xR020
PinHeader_1x02_P2.00mm_Vertical
C_0805_2012Metric x 2
VSSOP-10_3x3mm_P0.5mm
SOIC-16_3.9x9.9mm_P1.27mm
IRHub_V3_silkscreen
IRHub_V3_PCB

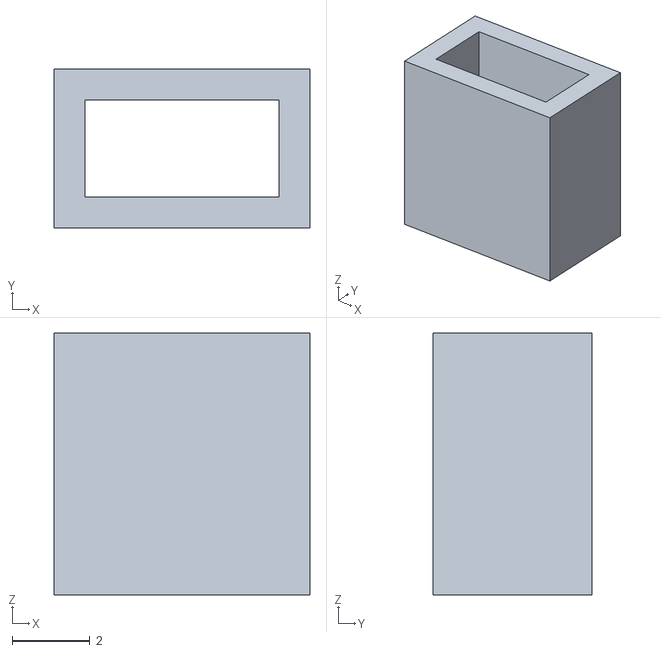
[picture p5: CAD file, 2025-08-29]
3D Print/PCB_Version/IRReceiverSupport Version 5.stl
6.60 x 4.10 x 6.75

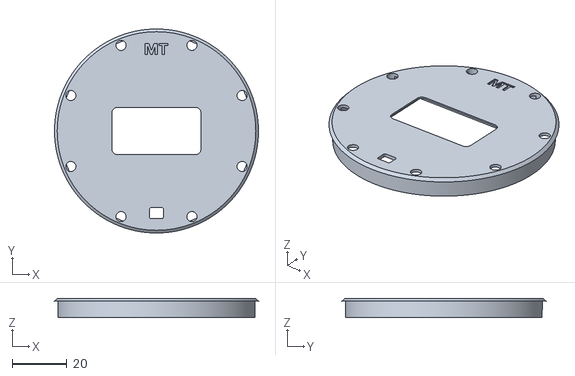
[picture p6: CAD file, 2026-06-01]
3D Print/Version 3/Top Cover.stl
74.5 x 74.5 x 7.00

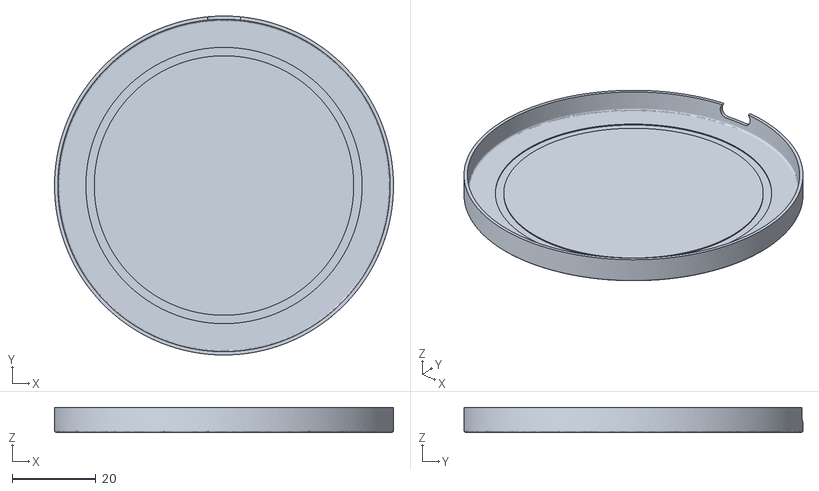
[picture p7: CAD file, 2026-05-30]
3D Print/Version 3/Base.stl
81.0 x 81.0 x 6.00

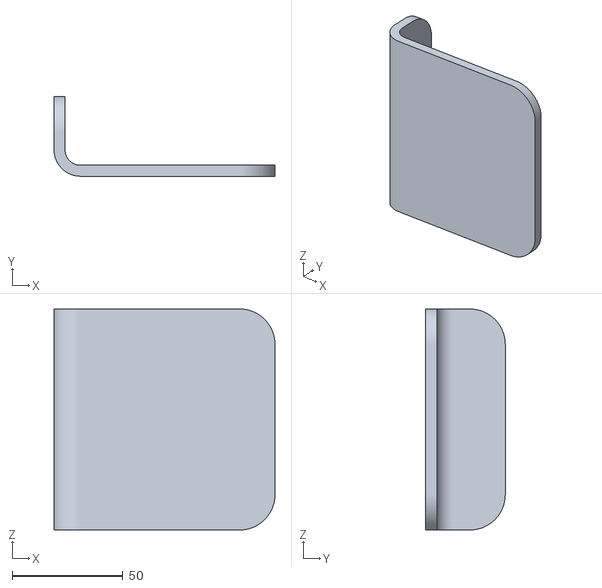
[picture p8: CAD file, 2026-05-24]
3D Print/Version 3/WallBase.stl
100.0 x 36.0 x 100.0

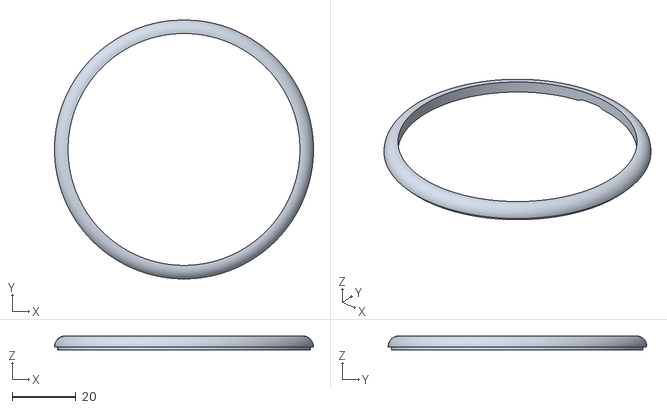
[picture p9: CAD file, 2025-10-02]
3D Print/Version 3/Led Ring.stl
81.0 x 80.9 x 4.50

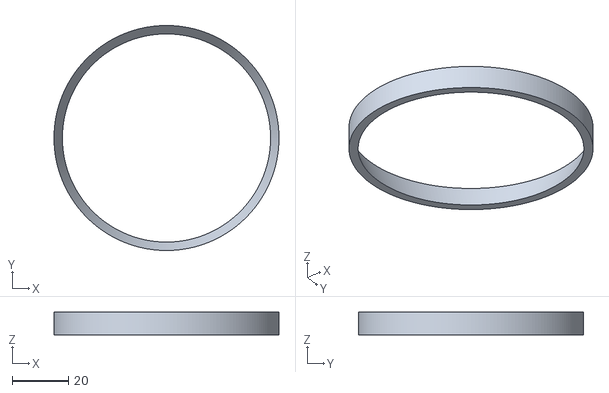
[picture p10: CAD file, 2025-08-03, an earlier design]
3D Print/Version 0/Outer Guide.stl
80.0 x 80.0 x 8.00

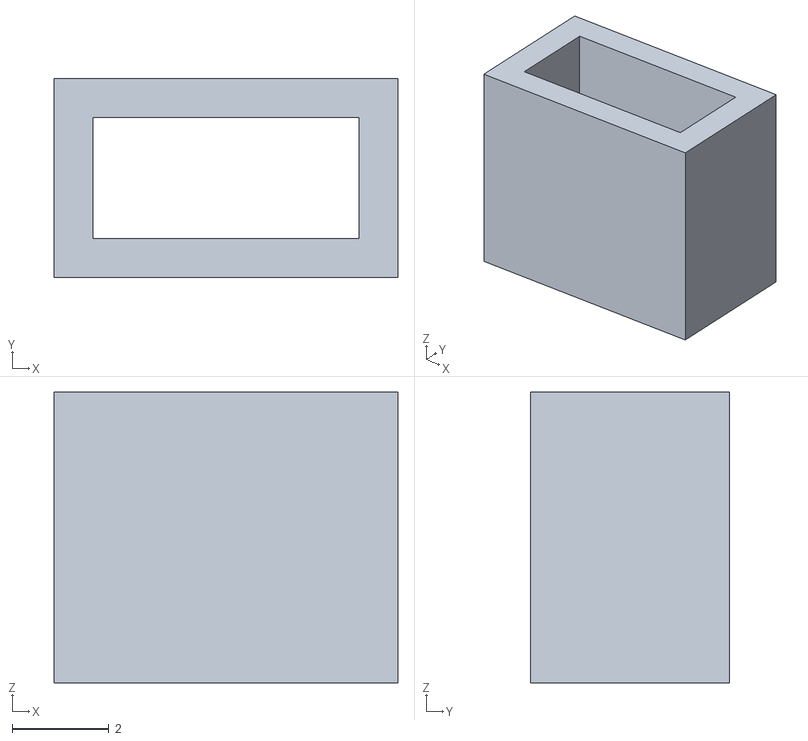
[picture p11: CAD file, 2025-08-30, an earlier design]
3D Print/Version 1/IRReceiverSupport.stl
7.10 x 4.10 x 6.00

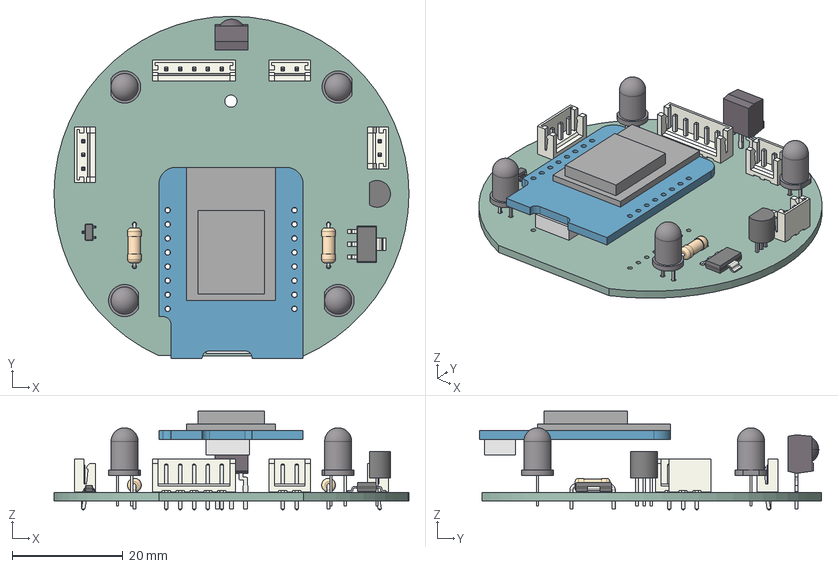
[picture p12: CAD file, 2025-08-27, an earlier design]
PCB/IRHub_PCB_V1/IRHub_PCB.step
64.0 x 61.7 x 17.8 mm
JST_EH_B2B-EH-A_1x02_P2.50mm_Vertical x 2
R_Axial_DIN0207_L6.3mm_D2.5mm_P7.62mm_Horizontal x 2
JST_EH_B3B-EH-A_1x03_P2.50mm_Vertical
Vishay_MOLD-3Pin
SOT-23
LED_D5.0mm_IRGrey x 4
WEMOS_D1_mini_light
JST_EH_B5B-EH-A_1x05_P2.50mm_Vertical
SOT-223
TO-92_Inline
IRHub_PCB_PCB

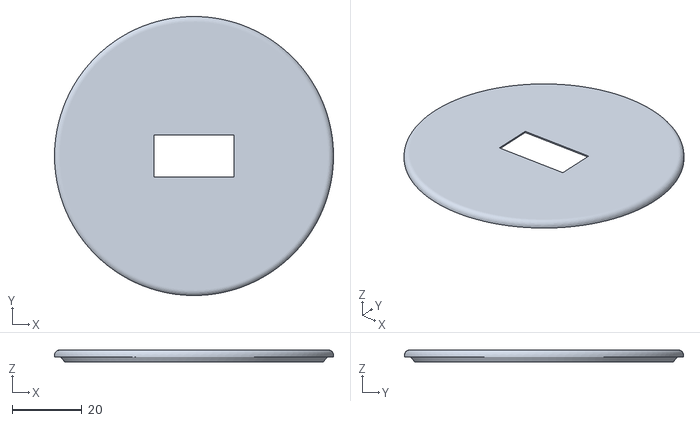
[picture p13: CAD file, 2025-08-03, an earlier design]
3D Print/Version 0/Top.stl
80.0 x 80.0 x 3.53

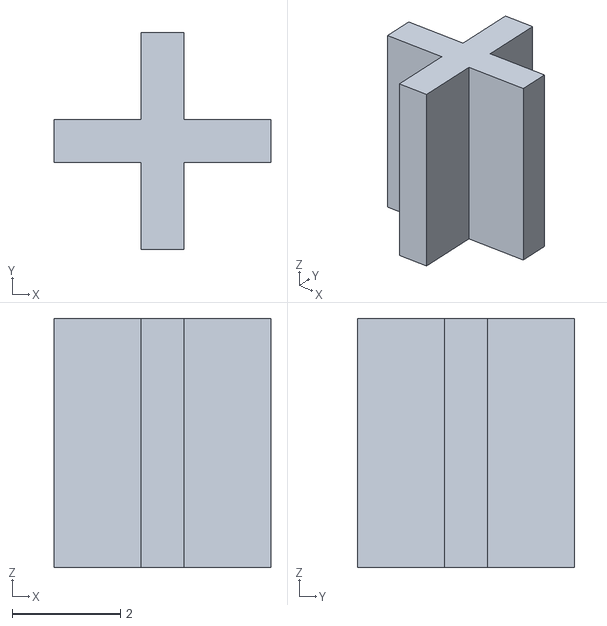
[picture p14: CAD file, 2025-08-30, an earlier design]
3D Print/Version 1/LedSupport.stl
4.00 x 4.00 x 4.60

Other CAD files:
PCB/IRHub_PCB_V3/IRHub_V3_Model.step
3D Print/Version 0/Led Ring.stl
3D Print/Version 1/Base5of5.stl
3D Print/Version 0/Speaker Holder.stl
3D Print/Version 0/Base.stl
3D Print/Version 0/IR Hub v0.f3d
3D Print/Version 0/IR Hub v13.f3d
3D Print/Version 0/IR Hub v26.f3d
3D Print/Version 0/IR Hub v5.f3d
3D Print/Version 0/Inner Guide.stl
3D Print/Version 0/Led Holder.stl
3D Print/Version 0/Led Mount Ring.stl
3D Print/Version 0/Led Support.stl
3D Print/Version 1/1.3InchOledPlateTest.stl
3D Print/Version 1/Base1of5.stl
3D Print/Version 1/Base2of5.stl
3D Print/Version 1/Base3of5.stl
3D Print/Version 1/Base4of5.stl
3D Print/Version 1/IR_Hub_PCB_Version v107.f3d
3D Print/Version 1/TopPlate.stl
3D Print/Version 3/IR Hub V3.f3z
PCB/IRHub_PCB_V3/IRHub_V3_Model.stl

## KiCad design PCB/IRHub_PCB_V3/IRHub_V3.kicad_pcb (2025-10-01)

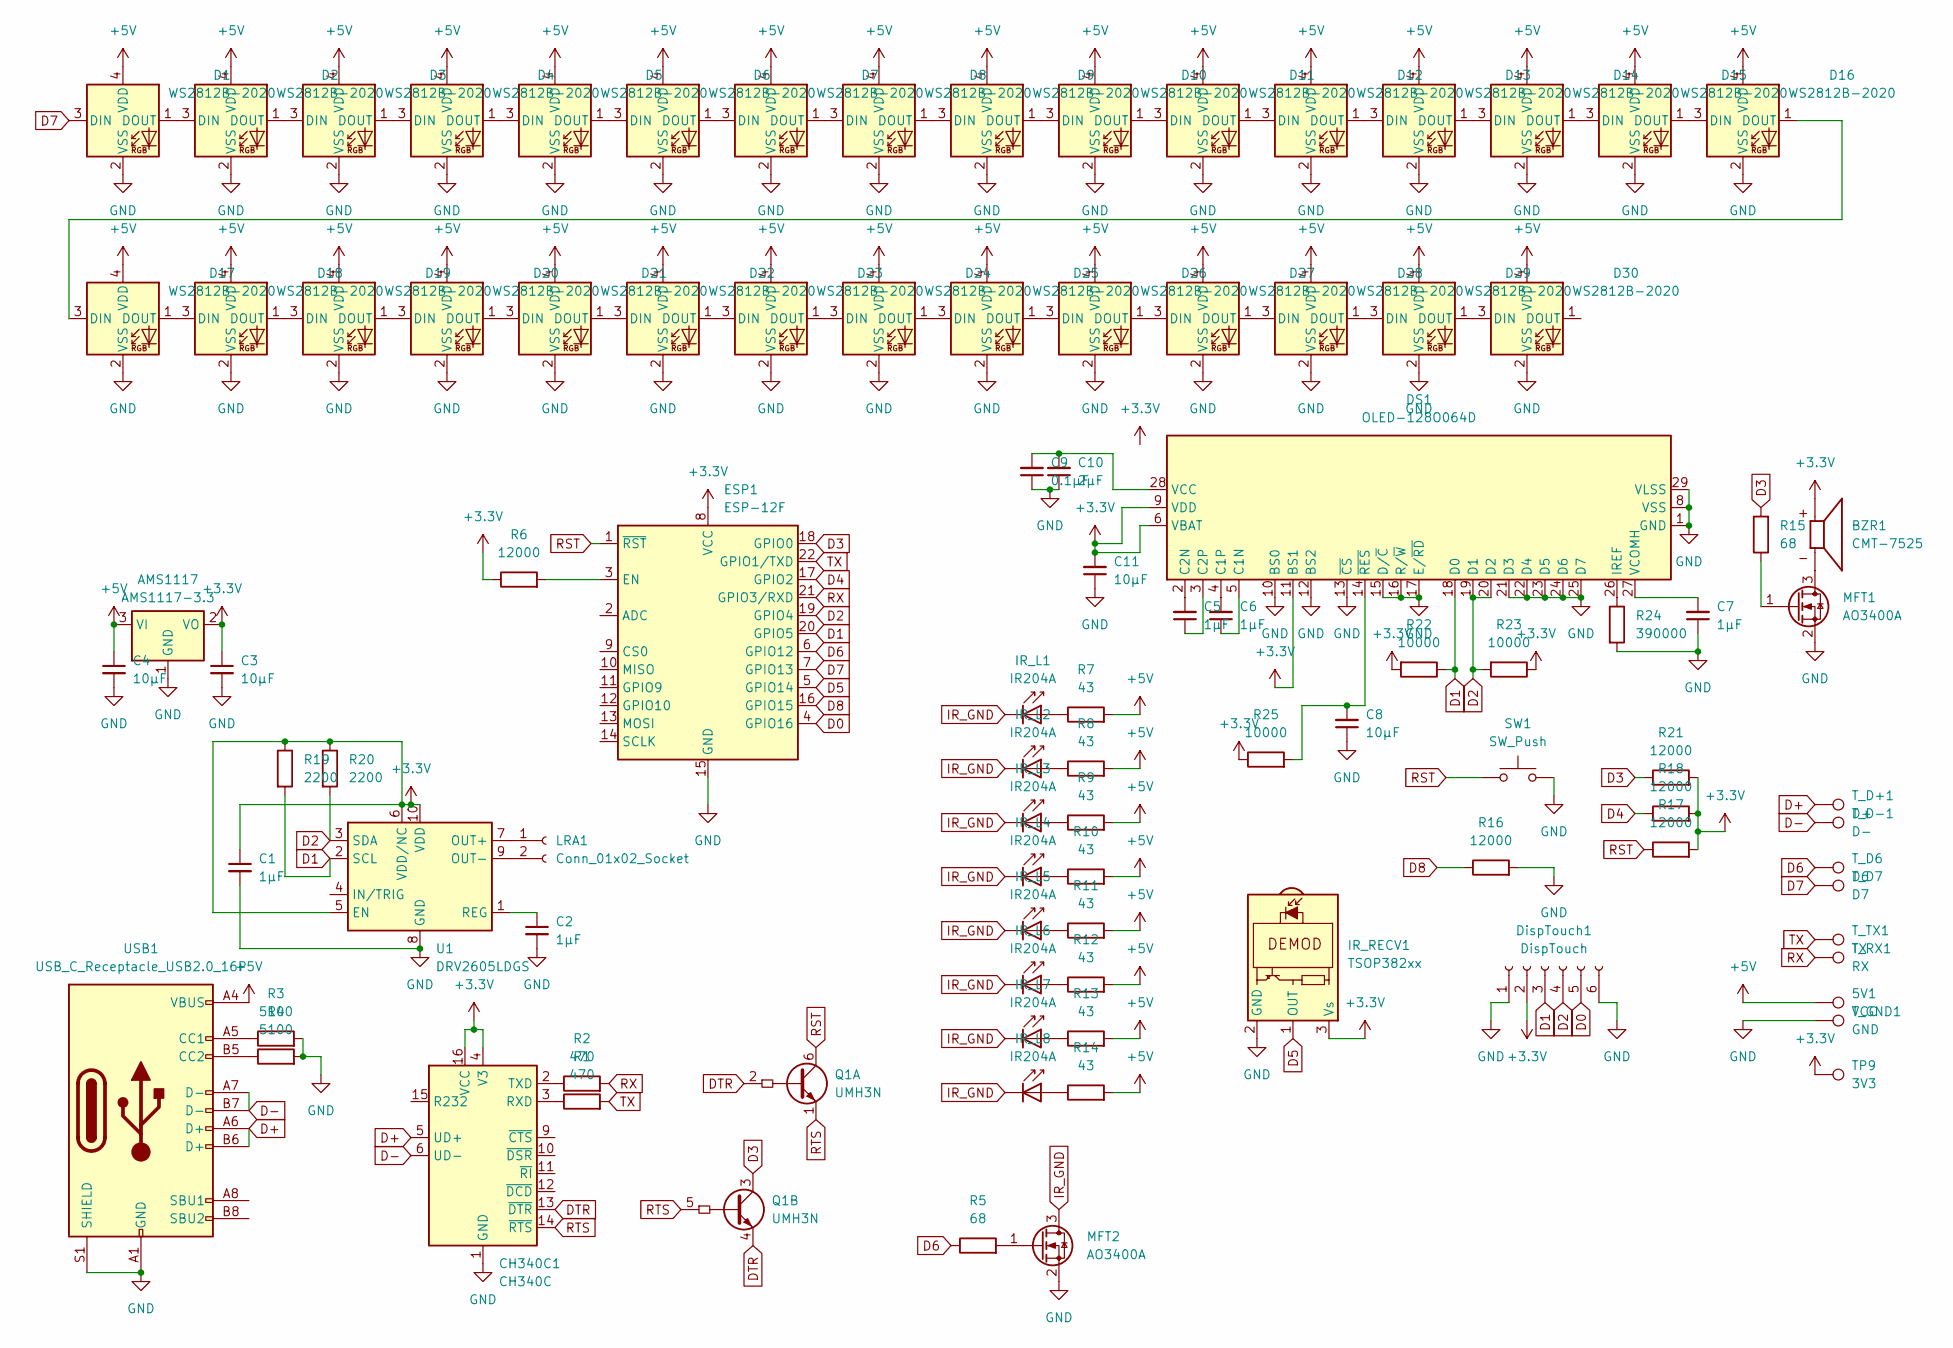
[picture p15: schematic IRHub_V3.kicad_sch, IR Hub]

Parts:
5V1: VCC; TestPoint_Pad_D1.0mm
AMS1117: AMS1117-3.3; SOT-223-3_TabPin2
BZR1: CMT-7525; XDCR_CMT-7525-80-SMT-TR; PARTREV N/A
C1, C2, C5, C6, C7: 1µF; C_0805_2012Metric_Pad1.18x1.45mm_HandSolder
C3, C4: 10µF; C_1206_3216Metric_Pad1.33x1.80mm_HandSolder
C8, C11: 10µF; C_0805_2012Metric_Pad1.18x1.45mm_HandSolder
C9: 0.1µF; C_0805_2012Metric_Pad1.18x1.45mm_HandSolder
C10: 2µF; C_0805_2012Metric_Pad1.18x1.45mm_HandSolder
CH340C1: CH340C; SOIC-16_3.9x9.9mm_P1.27mm
D1, D2, D3, D4, D5, D6, D7, D8, D9, D10, D11, D12, D13, D14, D15, D16, D17, D18, D19, D20, D21, D22, D23, D24, D25, D26, D27, D28, D29, D30: WS2812B-2020; LED_WS2812B-2020_PLCC4_2.0x2.0mm
DS1: OLED-128O064D
DispTouch1: DispTouch; JST_SH_BM06B-SRSS-TB_1x06-1MP_P1.00mm_Vertical
ESP1: ESP-12F; ESP-12E
IR_L1, IR_L2, IR_L3, IR_L4, IR_L5, IR_L6, IR_L7, IR_L8: IR204A; LED_D3.0mm_IRBlack
IR_RECV1: TSOP382xx; Vishay_MINICAST-3Pin
LRA1: Conn_01x02_Socket; PinHeader_1x02_P2.00mm_Vertical
MFT1, MFT2: AO3400A; SOT-23
Q1: UMH3N; SOT-363_SC-70-6
R1, R2: 470; R_1206_3216Metric
R3, R4: 5100; R_1206_3216Metric
R5, R15: 68; R_1206_3216Metric_Pad1.30x1.75mm_HandSolder
R6, R16, R17, R18, R21: 12000; R_1206_3216Metric_Pad1.30x1.75mm_HandSolder
R7, R8, R9, R10, R11, R12, R13, R14: 43; R_1210_3225Metric_Pad1.30x2.65mm_HandSolder
R19, R20: 2200; R_0805_2012Metric_Pad1.20x1.40mm_HandSolder
R22, R23, R25: 10000; R_0805_2012Metric_Pad1.20x1.40mm_HandSolder
R24: 390000; R_0805_2012Metric_Pad1.20x1.40mm_HandSolder
SW1: SW_Push; SW_SPST_TS-1088-xR020
TP9: 3V3; TestPoint_Pad_D1.0mm
T_D6: D6; TestPoint_Pad_D1.0mm
T_D7: D7; TestPoint_Pad_D1.0mm
T_D+1: D+; TestPoint_Pad_D1.0mm
T_D-1: D-; TestPoint_Pad_D1.0mm
T_GND1: GND; TestPoint_Pad_D1.0mm
T_RX1: RX; TestPoint_Pad_D1.0mm
T_TX1: TX; TestPoint_Pad_D1.0mm
U1: DRV2605LDGS; VSSOP-10_3x3mm_P0.5mm
USB1: USB_C_Receptacle_USB2.0_16P; USB_C_Receptacle_GCT_USB4110

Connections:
+3.3V: AMS1117.2 (VO), BZR1.P, C1.1, C3.1, C11.2, CH340C1.4 (V3), CH340C1.16 (VCC), DS1.6 (VBAT), DS1.9 (VDD), DS1.11 (BS1), DispTouch1.2, ESP1.8 (VCC), IR_RECV1.3 (Vs), R6.1, R17.2, R18.2, R19.1, R20.1, R21.2, R22.2, R23.1, R25.1, TP9.1, U1.5 (EN), U1.6 (VDD/NC), U1.10 (VDD)
+5V: 5V1.1, AMS1117.3 (VI), C4.1, D1.4 (VDD), D2.4 (VDD), D3.4 (VDD), D4.4 (VDD), D5.4 (VDD), D6.4 (VDD), D7.4 (VDD), D8.4 (VDD), D9.4 (VDD), D10.4 (VDD), D11.4 (VDD), D12.4 (VDD), D13.4 (VDD), D14.4 (VDD), D15.4 (VDD), D16.4 (VDD), D17.4 (VDD), D18.4 (VDD), D19.4 (VDD), D20.4 (VDD), D21.4 (VDD), D22.4 (VDD), D23.4 (VDD), D24.4 (VDD), D25.4 (VDD), D26.4 (VDD), D27.4 (VDD), D28.4 (VDD), D29.4 (VDD), D30.4 (VDD), R7.2, R8.2, R9.2, R10.2, R11.2, R12.2, R13.2, R14.2, USB1.A4 (VBUS), USB1.A9 (VBUS), USB1.B4 (VBUS), USB1.B9 (VBUS)
D0: DispTouch1.5, ESP1.4 (GPIO16)
D1: DS1.18 (D0), DispTouch1.3, ESP1.20 (GPIO5), R19.2, R22.1, U1.2 (SCL)
D2: DS1.19 (D1), DS1.20 (D2), DispTouch1.4, ESP1.19 (GPIO4), R20.2, R23.2, U1.3 (SDA)
D3: ESP1.18 (GPIO0), Q1.3 (C2), R15.2, R21.1
D4: ESP1.17 (GPIO2), R18.1
D5: ESP1.5 (GPIO14), IR_RECV1.1 (OUT)
D6: ESP1.6 (GPIO12), R5.1, T_D6.1
D7: D1.3 (DIN), ESP1.7 (GPIO13), T_D7.1
D8: ESP1.16 (GPIO15), R16.1
D+: CH340C1.5 (UD+), T_D+1.1, USB1.A6 (D+), USB1.B6 (D+)
D-: CH340C1.6 (UD-), T_D-1.1, USB1.A7 (D-), USB1.B7 (D-)
DTR: CH340C1.13 (~DTR), Q1.2 (B1), Q1.4 (E2)
GND: AMS1117.1 (GND), C1.2, C2.2, C3.2, C4.2, C7.1, C8.1, C9.1, C10.1, C11.1, CH340C1.1 (GND), D1.2 (VSS), D2.2 (VSS), D3.2 (VSS), D4.2 (VSS), D5.2 (VSS), D6.2 (VSS), D7.2 (VSS), D8.2 (VSS), D9.2 (VSS), D10.2 (VSS), D11.2 (VSS), D12.2 (VSS), D13.2 (VSS), D14.2 (VSS), D15.2 (VSS), D16.2 (VSS), D17.2 (VSS), D18.2 (VSS), D19.2 (VSS), D20.2 (VSS), D21.2 (VSS), D22.2 (VSS), D23.2 (VSS), D24.2 (VSS), D25.2 (VSS), D26.2 (VSS), D27.2 (VSS), D28.2 (VSS), D29.2 (VSS), D30.2 (VSS), DS1.1 (GND), DS1.8 (VSS), DS1.10 (BS0), DS1.12 (BS2), DS1.13 (~CS), DS1.15 (D/~C), DS1.16 (R/~W), DS1.17 (E/~RD), DS1.21 (D3), DS1.22 (D4), DS1.23 (D5), DS1.24 (D6), DS1.25 (D7), DS1.29 (VLSS), DS1.30 (GND), DispTouch1.1, DispTouch1.6, ESP1.15 (GND), IR_RECV1.2 (GND), MFT1.2 (S), MFT2.2 (S), R3.2, R4.2, R16.2, R24.2, SW1.2, T_GND1.1, U1.8 (GND), USB1.A1 (GND), USB1.A12 (GND), USB1.B1 (GND), USB1.B12 (GND), USB1.S1 (SHIELD)
IR_GND: IR_L1.1 (K), IR_L2.1 (K), IR_L3.1 (K), IR_L4.1 (K), IR_L5.1 (K), IR_L6.1 (K), IR_L7.1 (K), IR_L8.1 (K), MFT2.3 (D)
unnamed: CH340C1.3 (RXD), R1.1
unnamed: CH340C1.2 (TXD), R2.1
unnamed: D1.1 (DOUT), D2.3 (DIN)
unnamed: D2.1 (DOUT), D3.3 (DIN)
unnamed: D3.1 (DOUT), D4.3 (DIN)
unnamed: D4.1 (DOUT), D5.3 (DIN)
unnamed: D5.1 (DOUT), D6.3 (DIN)
unnamed: D6.1 (DOUT), D7.3 (DIN)
unnamed: D7.1 (DOUT), D8.3 (DIN)
unnamed: D8.1 (DOUT), D9.3 (DIN)
unnamed: D9.1 (DOUT), D10.3 (DIN)
unnamed: D10.1 (DOUT), D11.3 (DIN)
unnamed: D11.1 (DOUT), D12.3 (DIN)
unnamed: D12.1 (DOUT), D13.3 (DIN)
unnamed: D13.1 (DOUT), D14.3 (DIN)
unnamed: D14.1 (DOUT), D15.3 (DIN)
unnamed: D15.1 (DOUT), D16.3 (DIN)
unnamed: D16.1 (DOUT), D17.3 (DIN)
unnamed: D17.1 (DOUT), D18.3 (DIN)
unnamed: D18.1 (DOUT), D19.3 (DIN)
unnamed: D19.1 (DOUT), D20.3 (DIN)
unnamed: D20.1 (DOUT), D21.3 (DIN)
unnamed: D21.1 (DOUT), D22.3 (DIN)
unnamed: D22.1 (DOUT), D23.3 (DIN)
unnamed: D23.1 (DOUT), D24.3 (DIN)
unnamed: D24.1 (DOUT), D25.3 (DIN)
unnamed: D25.1 (DOUT), D26.3 (DIN)
unnamed: D26.1 (DOUT), D27.3 (DIN)
unnamed: D27.1 (DOUT), D28.3 (DIN)
unnamed: D28.1 (DOUT), D29.3 (DIN)
unnamed: D29.1 (DOUT), D30.3 (DIN)
unnamed: C6.1, DS1.5 (C1N)
unnamed: C6.2, DS1.4 (C1P)
unnamed: C5.2, DS1.2 (C2N)
unnamed: C5.1, DS1.3 (C2P)
unnamed: DS1.26 (IREF), R24.1
unnamed: C9.2, C10.2, DS1.28 (VCC)
unnamed: C7.2, DS1.27 (VCOMH)
unnamed: C8.2, DS1.14 (~RES), R25.2
unnamed: ESP1.3 (EN), R6.2
unnamed: IR_L1.2 (A), R7.1
unnamed: IR_L2.2 (A), R8.1
unnamed: IR_L3.2 (A), R9.1
unnamed: IR_L4.2 (A), R10.1
unnamed: IR_L5.2 (A), R11.1
unnamed: IR_L6.2 (A), R12.1
unnamed: IR_L7.2 (A), R13.1
unnamed: IR_L8.2 (A), R14.1
unnamed: LRA1.1, U1.7 (OUT+)
unnamed: LRA1.2, U1.9 (OUT-)
unnamed: BZR1.N, MFT1.3 (D)
unnamed: MFT1.1 (G), R15.1
unnamed: MFT2.1 (G), R5.2
unnamed: C2.1, U1.1 (REG)
unnamed: R3.1, USB1.A5 (CC1)
unnamed: R4.1, USB1.B5 (CC2)
RST: ESP1.1 (~RST), Q1.6 (C1), R17.1, SW1.1
RTS: CH340C1.14 (~RTS), Q1.1 (E1), Q1.5 (B2)
RX: ESP1.21 (GPIO3/RXD), R2.2, T_RX1.1
TX: ESP1.22 (GPIO1/TXD), R1.2, T_TX1.1

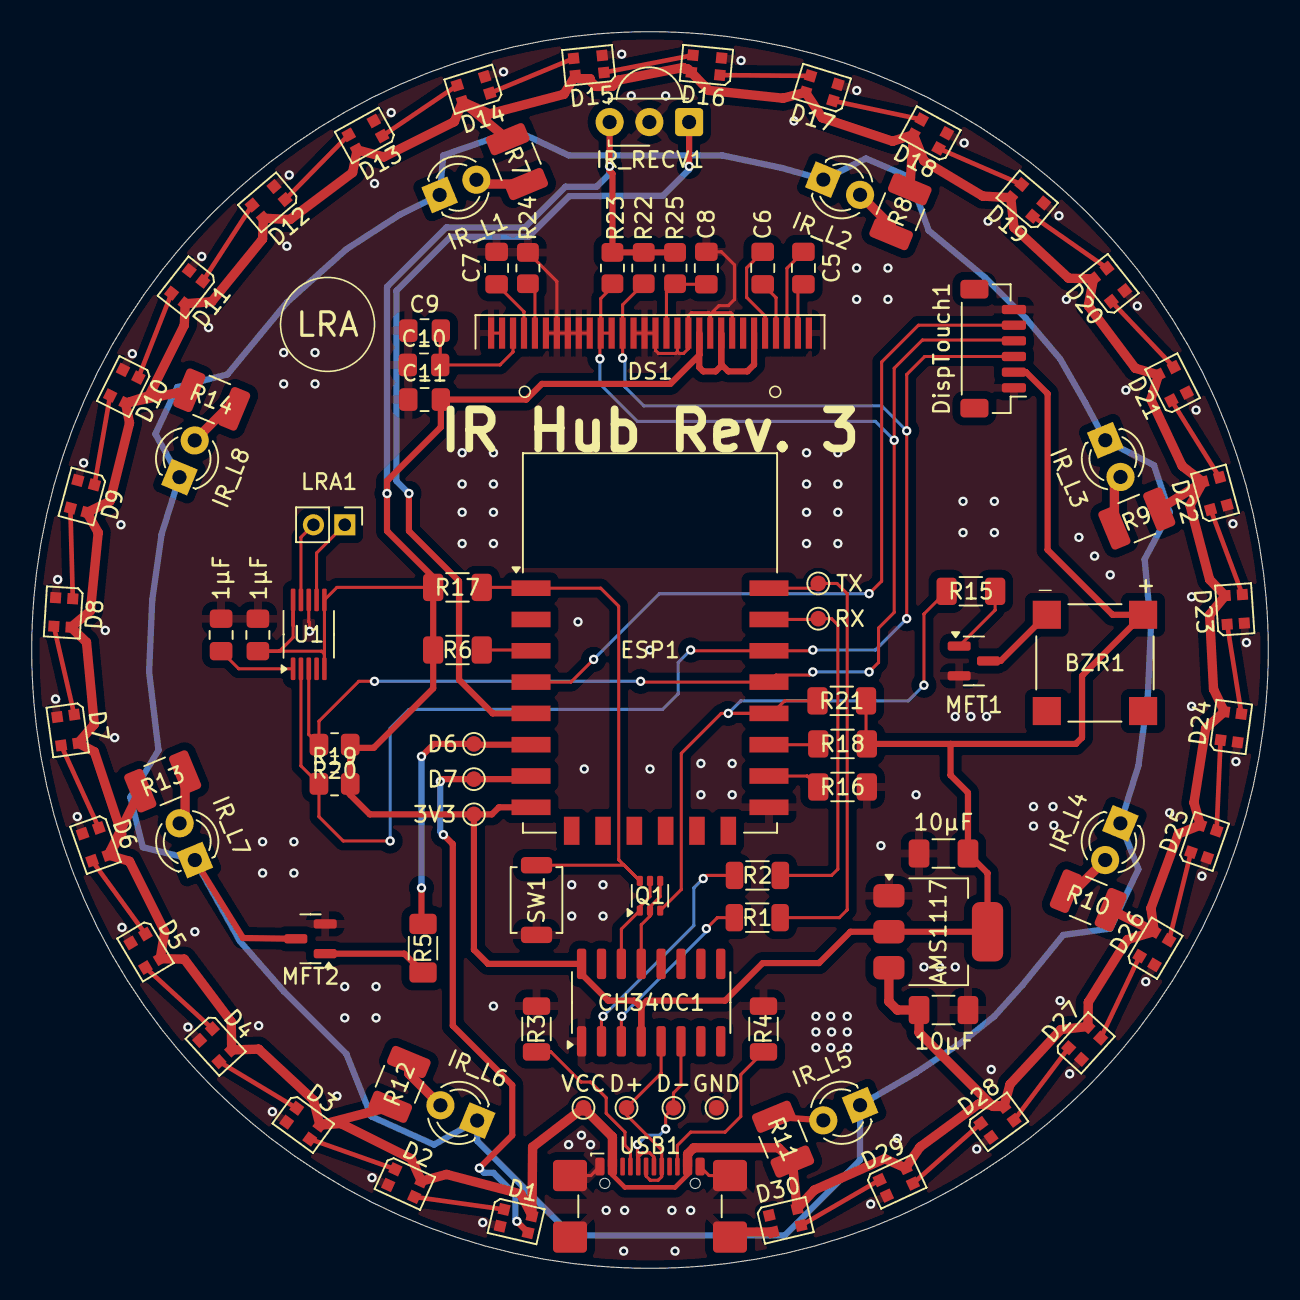
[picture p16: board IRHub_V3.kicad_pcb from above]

Board: 2 copper layers, 79.0 x 79.0 mm, 97 parts (0 on the bottom side), 76 nets.

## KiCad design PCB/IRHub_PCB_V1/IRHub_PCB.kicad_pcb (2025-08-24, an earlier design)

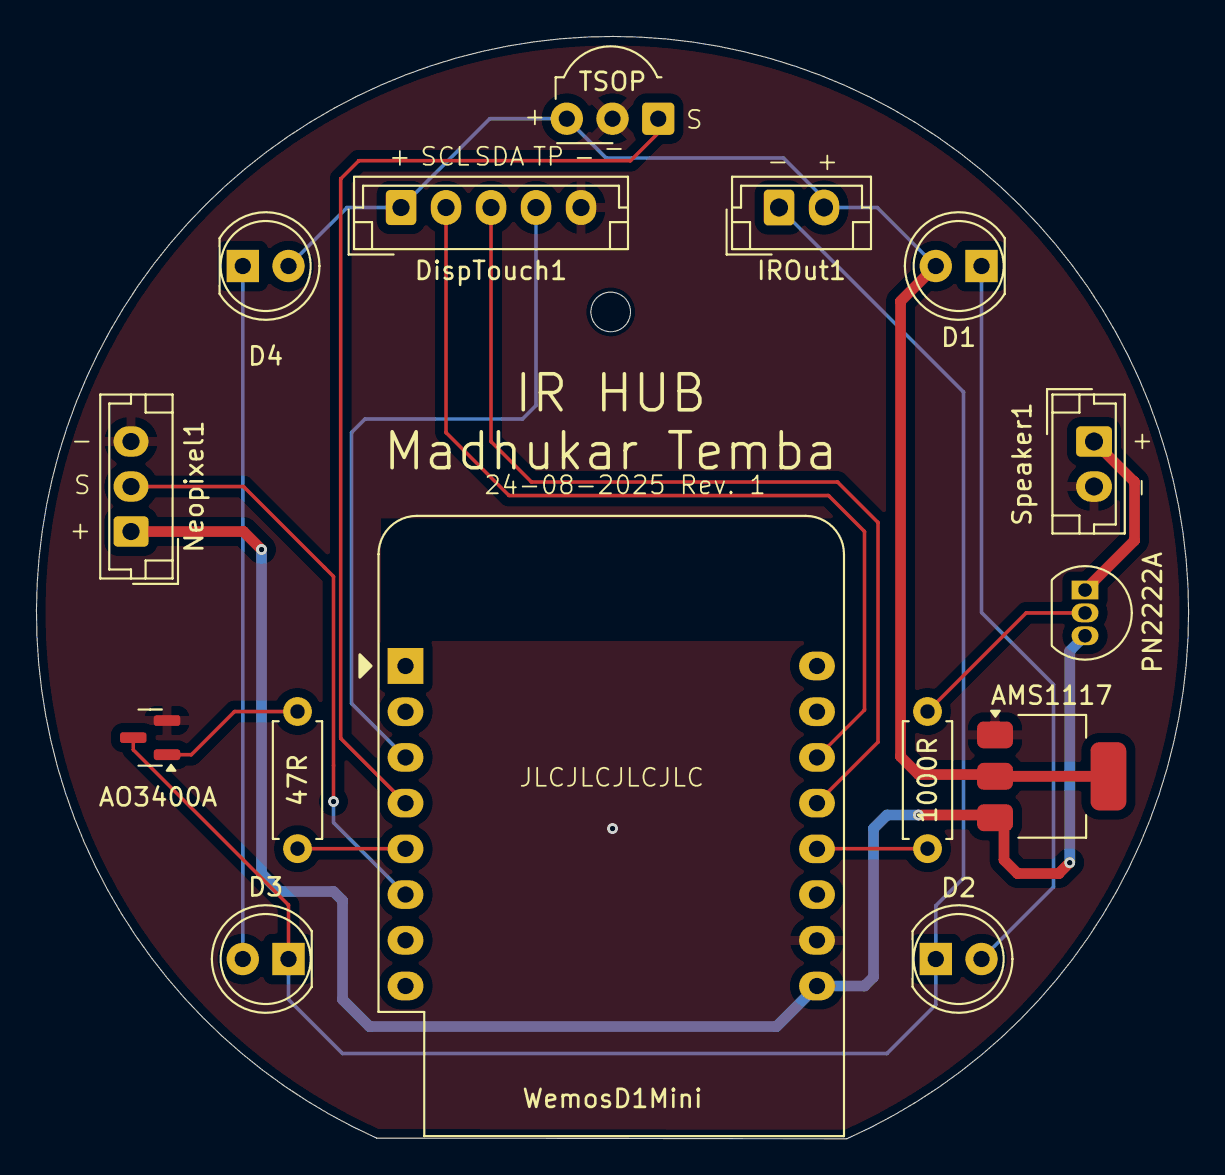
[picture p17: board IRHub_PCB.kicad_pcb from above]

Board: 2 copper layers, 64.0 x 61.2 mm, 15 parts (0 on the bottom side), 16 nets.

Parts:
47R: 47; R_Axial_DIN0207_L6.3mm_D2.5mm_P7.62mm_Horizontal
1000R: 1000; R_Axial_DIN0207_L6.3mm_D2.5mm_P7.62mm_Horizontal
AMS1117: AMS1117-3.3; SOT-223-3_TabPin2
AO3400A: AO3400A; SOT-23
D1, D2, D3, D4: LD271; LED_D5.0mm_IRGrey
DispTouch1: Conn_01x05_Pin; JST_EH_B5B-EH-A_1x05_P2.50mm_Vertical
IROut1: Conn_01x02_Pin; JST_EH_B2B-EH-A_1x02_P2.50mm_Vertical
Neopixel1: Conn_01x03_Pin; JST_EH_B3B-EH-A_1x03_P2.50mm_Vertical
PN2222A: PN2222A; TO-92_Inline
Speaker1: Conn_01x02_Pin; JST_EH_B2B-EH-A_1x02_P2.50mm_Vertical
TSOP: TSOP43xx; Vishay_MOLD-3Pin
WemosD1Mini: WEMOS_D1_mini; WEMOS_D1_mini_light

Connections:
+3.3V: AMS1117.2 (VO), D1.2 (A), D4.2 (A), DispTouch1.1, IROut1.2, TSOP.3 (Vs)
+5V: AMS1117.3 (VI), Neopixel1.1, PN2222A.3 (C), WemosD1Mini.9 (5V)
GND: AMS1117.1 (GND), AO3400A.2 (S), DispTouch1.5, Neopixel1.3, Speaker1.2, TSOP.2 (GND), WemosD1Mini.10 (GND)
unnamed: D1.1 (K), D2.2 (A)
unnamed: AO3400A.3 (D), D2.1 (K), D3.1 (K), IROut1.1
unnamed: D3.2 (A), D4.1 (K)
unnamed: DispTouch1.2, WemosD1Mini.14 (SCL/D1)
unnamed: DispTouch1.3, WemosD1Mini.13 (SDA/D2)
unnamed: DispTouch1.4, WemosD1Mini.3 (D0)
unnamed: Neopixel1.2, WemosD1Mini.6 (MOSI/D7)
unnamed: 1000R.2, PN2222A.2 (B)
unnamed: PN2222A.1 (E), Speaker1.1
unnamed: 47R.2, AO3400A.1 (G)
unnamed: 1000R.1, WemosD1Mini.12 (D3)
unnamed: 47R.1, WemosD1Mini.5 (MISO/D6)
unnamed: TSOP.1 (OUT), WemosD1Mini.4 (SCK/D5)

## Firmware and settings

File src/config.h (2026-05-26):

#ifndef CONFIG_H
#define CONFIG_H

#ifdef USE_VERSION_0
#    define DISPLAY_TYPE DisplayType::SSD1306
#    define DISPLAY_FLIPPED true

#    define TOUCH_BUTTON_PIN D0
#    define OLED_SCL_PIN D1
#    define OLED_SDA_PIN D2
#    define SPEAKER_PIN D3
#    define IR_RX_PIN D5
#    define IR_TX_PIN D6
#    define NEOPIXEL_PIN D7

#    define NUM_LEDS 13  // Number of LEDs in the circular strip
#    define DISPLAY_DRIVER DisplayDriver::FASTLED

#    define WIFI_AP_NAME "IRHub V0 Setup"
#    define WIFI_AP_TIMEOUT 180  // 3 minutes timeout

#endif  // USE_VERSION_0

#ifdef USE_VERSION_1

#    define DISPLAY_TYPE DisplayType::SH1106
#    define DISPLAY_FLIPPED false

#    define TOUCH_BUTTON_PIN D0
#    define OLED_SCL_PIN D1
#    define OLED_SDA_PIN D2
#    define SPEAKER_PIN D3
#    define IR_RX_PIN D5
#    define IR_TX_PIN D6
#    define NEOPIXEL_PIN D7

#    define NUM_LEDS 27  // Number of LEDs in the circular strip
#    define DISPLAY_DRIVER DisplayDriver::NEOPIXEL

#    define WIFI_AP_NAME "IRHub V1 Setup"
#    define WIFI_AP_TIMEOUT 180  // 3 minutes timeout

#endif  // USE_VERSION_1

#ifdef USE_VERSION_3

#    define DISPLAY_TYPE DisplayType::SH1106
#    define DISPLAY_FLIPPED false

#    define TOUCH_BUTTON_PIN D0
#    define OLED_SCL_PIN D1
#    define OLED_SDA_PIN D2
#    define SPEAKER_PIN D3
#    define IR_RX_PIN D5
#    define IR_TX_PIN D6
#    define NEOPIXEL_PIN D7

#    define NUM_LEDS 30  // Number of LEDs in the circular strip
#    define DISPLAY_DRIVER DisplayDriver::NEOPIXEL

#    define WIFI_AP_NAME "IRHub V3 Setup"
#    define WIFI_AP_TIMEOUT 180  // 3 minutes timeout

#endif  // USE_VERSION_3

#endif  // CONFIG_H

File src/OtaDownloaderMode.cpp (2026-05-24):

#include "OtaDownloaderMode.h"

#include <ESP8266WiFi.h>
#include <Updater.h>
#include <WiFiClientSecure.h>
#include <Wire.h>
#include "BootSafety.h"
#include "Global/Global.h"
#include "config.h"
#include "preferences.h"

namespace ota_downloader {

namespace {

// TLS receive buffer for the firmware download. We must use 16KB (the TLS maximum)
// because Cloudflare Pages does not reliably support MFLN (Max Fragment Length Negotiation)
// and sends full 16KB records for large files. This fits in our ~27KB downloader-mode
// heap because the BearSSL handshake transient memory (~4KB) is freed before Update.begin()
// allocates its flash buffer (~4KB).
constexpr int kDownloaderTlsRxBuffer = 16384;
constexpr int kDownloaderTlsTxBuffer = 512;

U8G2* g_dlDisplay = nullptr;

void downloaderShowStatus(const char* line1, const char* line2 = nullptr) {
    if (!g_dlDisplay) {
        return;
    }
    g_dlDisplay->firstPage();
    do {
        g_dlDisplay->setFont(u8g2_font_helvR08_tr);
        int w = g_dlDisplay->getStrWidth("Firmware Update");
        g_dlDisplay->drawStr((128 - w) / 2, 12, "Firmware Update");
        g_dlDisplay->drawLine(0, 18, 128, 18);
        if (line1) {
            w = g_dlDisplay->getStrWidth(line1);
            g_dlDisplay->drawStr((128 - w) / 2, 34, line1);
        }
        if (line2) {
            w = g_dlDisplay->getStrWidth(line2);
            g_dlDisplay->drawStr((128 - w) / 2, 48, line2);
        }
    } while (g_dlDisplay->nextPage());
}

void downloaderShowProgress(const char* version, size_t cur, size_t total) {
    if (!g_dlDisplay) {
        return;
    }

    ledRing.update();

    char title[32];
    snprintf(title, sizeof(title), "Installing v%s", version);
    char pct[8];
    unsigned p =
        (total > 0) ? (unsigned)(((unsigned long)cur * 100UL) / (unsigned long)total) : 0;
    snprintf(pct, sizeof(pct), "%u%%", p);

    g_dlDisplay->firstPage();
    do {
        g_dlDisplay->setFont(u8g2_font_helvR08_tr);
        int w = g_dlDisplay->getStrWidth(title);
        g_dlDisplay->drawStr((128 - w) / 2, 12, title);
        g_dlDisplay->drawLine(0, 20, 128, 20);

        g_dlDisplay->drawFrame(10, 32, 108, 14);
        if (total > 0) {
            int bw = (int)(104UL * cur / total);
            if (bw > 0) {
                g_dlDisplay->drawBox(12, 34, bw, 10);
            }
        }

        w = g_dlDisplay->getStrWidth(pct);
        g_dlDisplay->drawStr((128 - w) / 2, 60, pct);
    } while (g_dlDisplay->nextPage());
}

bool downloaderStreamUpdate(WiFiClientSecure& client, const char* url, const char* version,
                            size_t expectedSize, const char* md5Hex) {
    // Parse URL to avoid String allocations
    const char* urlPath = url;
    if (strncmp(urlPath, "https://", 8) == 0) {
        urlPath += 8;
    } else if (strncmp(urlPath, "http://", 7) == 0) {
        urlPath += 7;
    }

    const char* slash = strchr(urlPath, '/');
    if (!slash) {
        slash = "/";
    }

    char host[64];
    size_t hostLen = slash > urlPath ? slash - urlPath : 0;
    if (hostLen >= sizeof(host)) {
        hostLen = sizeof(host) - 1;
    }
    strncpy(host, urlPath, hostLen);
    host[hostLen] = '\0';

    if (!client.connect(host, 443)) {
        return false;
    }

    client.print("GET ");
    client.print(slash);
    client.print(" HTTP/1.0\r\nHost: ");
    client.print(host);
    client.print("\r\nUser-Agent: IRHub-OTA/");
    client.print(version);
    client.print("\r\nConnection: close\r\n\r\n");

    // Read headers manually to save HTTPClient overhead (~300 bytes)
    char c;
    int newlines = 0;
    unsigned long timeout = millis() + 10000UL;
    while (client.connected() || client.available()) {
        if (millis() > timeout) {
            return false;
        }
        if (!client.available()) {
            delay(1);
            continue;
        }
        c = client.read();
        if (c == '\n') {
            newlines++;
        } else if (c != '\r') {
            newlines = 0;
        }
        if (newlines == 2) {
            break;
        }
    }

    if (newlines != 2) {
        return false;
    }

    if (!Update.begin(expectedSize, U_FLASH)) {
        return false;
    }
    if (md5Hex && *md5Hex) {
        Update.setMD5(md5Hex);
    }

    uint8_t buf[512];
    size_t written = 0;
    unsigned long lastProgress = millis();
    unsigned long lastByteAt = millis();
    constexpr unsigned long kStreamIdleTimeoutMs = 20000UL;

    while (written < expectedSize) {
        int avail = client.available();
        if (avail <= 0) {
            if (!client.connected() && client.available() <= 0) {
                break;
            }
            if (millis() - lastByteAt > kStreamIdleTimeoutMs) {
                break;
            }
            delay(1);
            continue;
        }
        size_t toRead = (size_t)avail < sizeof(buf) ? (size_t)avail : sizeof(buf);
        if (toRead > expectedSize - written) {
            toRead = expectedSize - written;
        }
        int n = client.readBytes(buf, toRead);
        if (n <= 0) {
            break;
        }
        if (Update.write(buf, (size_t)n) != (size_t)n) {
            Update.end(false);
            return false;
        }
        written += (size_t)n;
        lastByteAt = millis();
        if (millis() - lastProgress > 250) {
            downloaderShowProgress(version, written, expectedSize);
            lastProgress = millis();
        }
    }

    if (written != expectedSize) {
        Update.end(false);
        return false;
    }

    if (!Update.end(true)) {
        return false;
    }
    downloaderShowProgress(version, expectedSize, expectedSize);
    return true;
}

}  // namespace
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

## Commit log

2025-08-03 add 3d print files
    [Base.stl, IR Hub v0.f3d, IR Hub v13.f3d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]
2025-08-03 add pin defs
2025-08-03 simple button test
2025-08-07 led ring test
2025-08-07 change number of leds
2025-08-08 add lib prop
2025-08-08 center led
2025-08-08 use button
2025-08-08 button fix
2025-08-08 update center led
2025-08-09 add new button
2025-08-10 add little fs mount
2025-08-12 add device manager lib
2025-08-12 add lib prop to log
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2025-08-12 mock dual device add
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2025-08-12 add delete device option
2025-08-12 complete single mode and add back button to devices
2025-08-12 add clear data button
2025-08-12 rename ir learn to add device
2025-08-12 fix back button bug hopefully; g
2025-08-13 fix device added text
2025-08-13 remove modes from add device
2025-08-13 ai led control test
2025-08-13 Revert "ai led control test"
    This reverts commit 169b3a091ab879fb35673aed82ea279ee4a07e92.
    [DeviceDetails.h]
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2025-08-16 add device manager cache
2025-08-16 add alexa connector to main
2025-08-17 add reset wifi settings option
    [config.h]
2025-08-19 fixed led lib
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2025-08-20 change homescreen button behaviour
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2025-08-22 add fauxmo alexa connector as well for future reference
2025-08-22 revert button sound
2025-08-22 add beeps in add device
2025-08-22 new log tests on alexa connector
2025-08-22 Revert "new log tests on alexa connector"
    This reverts commit bcfabeec72867758a578b9e219d1f6f941118590.
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2025-08-22 fix fast led version
2025-08-22 Revert "fix fast led version"
    This reverts commit 05828b967562b2f1cf58f5daff040834bfbdcdff.
2025-08-24 add pcb file
    [IRHub_PCB-B_Cu.gbr, IRHub_PCB-B_Mask.gbr, IRHub_PCB-B_Paste.gbr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]
2025-08-24 rename folder
    [IRHub_PCB-B_Cu.gbr, IRHub_PCB-B_Mask.gbr, IRHub_PCB-B_Paste.gbr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]
2025-08-27 add step file
    [IRHub_PCB.step]
2025-08-28 add base 3d print
    [Base Version 1.stl]
2025-08-28 add new body
    [Body Version 2.stl, Top Version 2.stl]
2025-08-28 update 3d file slightly
    [Body Version 2.stl]
2025-08-28 add oled plate test
    [1.3InchOledPlateTest.stl, PCB_IR_Hub_Params.csv]
2025-08-28 add supports
    [IRReceiverSupport.stl, LedSupport.stl]
2025-08-28 minor tweaks
    [1.3InchOledPlateTest.stl]
2025-08-28 add ver 3
    [Base Version 3.stl, IRReceiverSupport Version 3.stl, LedSupport Version 3.stl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]
2025-08-28 remove old versions
    [Base Version 1.stl, Body Version 2.stl, IRReceiverSupport.stl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]
2025-08-29 add version 4
    [Base Version 4.stl]
2025-08-29 add logo
    [Base Version 4.stl]
2025-08-29 add ver 4 files
    [IRReceiverSupport Version 4.stl, LedSupport Version 4.stl, TopPlate Version 4.stl]
2025-08-29 remove older versions
    [IRReceiverSupport Version 3.stl, LedSupport Version 3.stl, TopPlate Version 3.stl]
2025-08-29 ver 5 base
    [Base Version 5.stl]
2025-08-29 add ver 5 supports
    [IRReceiverSupport Version 5.stl, LedSupport Version 5.stl]
2025-08-29 rename files
    [Base Version 4.stl, Base.stl, IRReceiverSupport Version 4.stl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]
2025-08-29 add f360 file
    [IR_Hub_PCB_Version v107.f3d]
2025-08-29 add sno bases
    [Base2of5.stl, Base3of5.stl, Base4of5.stl]
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2025-08-30 hieght update
    [IRReceiverSupport.stl, LedSupport.stl]
2025-09-13 add pcb v3
    [CMT-7525-80-SMT-TR.step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]
2025-09-13 complete schematic i think ?
    [IRHub_V3.kicad_pcb, IRHub_V3.kicad_sch]
2025-09-13 try to arrange leds in a circle
    [IRHub_V3.kicad_pcb]
2025-09-14 final design i think
    [IRHub_V3.kicad_pcb, IRHub_V3.kicad_sch]
2025-09-14 added haptics
    [IRHub_V3.kicad_pcb, IRHub_V3.kicad_sch]
2025-09-14 power pcb done
    [IRHub_V3.kicad_pcb, IRHub_V3.kicad_sch]
2025-09-15 finished placement
    [IRHub_V3.kicad_pcb, IRHub_V3.kicad_sch]
2025-09-15 update resistor values
    [IRHub_V3.kicad_pcb, IRHub_V3.kicad_sch]
2025-09-15 complete pcb design
    [IRHub_V3.kicad_pcb]
2025-09-15 final board design i hope
    [IRHub_V3.kicad_pcb, IRHub_V3.kicad_sch]
2025-09-15 added one missing res 👀
    [IRHub_V3.kicad_pcb, IRHub_V3.kicad_sch]
2025-09-15 generated gerber
    [IRHub_V3-B_Cu.gbl, IRHub_V3-B_Mask.gbs, IRHub_V3-B_Paste.gbp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]
2025-09-15 generate pcb using plugin
    [IRHub_V3-B_Cu.gbl, IRHub_V3-B_Mask.gbs, IRHub_V3-B_Paste.gbp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]
2025-09-15 some auto updates by kicad
2025-09-22 fix pcb led issue :)
    [IRHub_V3.kicad_pcb, IRHub_V3.kicad_sch, IRHub_V3.step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]
2025-09-22 new pcb
    [IRHub_V3.kicad_pcb]
2025-09-22 add vias
    [IRHub_V3.kicad_pcb]
2025-09-23 small space savings for the oled conn
    [IRHub_V3.kicad_pcb]
2025-09-23 new updated version with oled connector
    [IRHub_V3.kicad_pcb, IRHub_V3.kicad_sch]
2025-09-23 final production build, hope I didn't mess something up this time :)
    [IRHub_V3.kicad_pcb, bom.csv, designators.csv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]
2025-09-27 add prototype 3d print file
    [Base.stl, Led Ring.stl]
2025-09-27 change resolution
    [Base.stl, IR Hub V3 v46.f3z, Led Ring.stl]
2025-09-30 new 3d file
    [Base.stl, IR Hub V3 v54.f3z, Led Ring.stl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]
2025-09-30 add version 3
    [Led Ring.stl]
2025-10-01 fix oled connector wiring
    [Base.stl, IRHub_V3.kicad_pcb, IRHub_V3.kicad_sch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]
2025-10-01 update stls
    [Base.stl, Led Ring.stl]
2025-10-02 final 3d print files I hpe
    [Base.stl, IR Hub V3 v46.f3z, IR Hub V3 v54.f3z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]
2025-10-11 add engine and driver
2025-10-11 add fast led driver
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2025-10-12 switch to new led lib
2025-10-12 switch to solid color while recording
2025-10-12 remove led ring lib
2025-10-12 limit display frame rate
2025-10-12 remove center led config
2025-10-12 add display driver selection
2025-10-13 switch to the git version of neo ring library
2026-03-26 add basic connector impl
2026-03-28 fix stuck pixel issue in v3
    [HomeScreen.h]
2026-05-23 fix boot loop delay and attempt recovery
    [DeviceDetails.h]
2026-05-23 chore(ota): serve firmware binaries via jsDelivr instead of GitHub Releases
    The device kept OOM-crashing during the binary download because
    objects.githubusercontent.com doesn't negotiate TLS MFLN, forcing
    BearSSL to allocate full-size 16 KB records that don't fit in the
    ESP8266's ~14 KB free heap.
    release.py now also commits each firmware as
    binaries/firmware_<variant>_v<version>.bin, and the manifest URL points
    at cdn.jsdelivr.net (same MFLN-friendly edge as the manifest itself).
    The GitHub Release still gets the binary attached for human visibility,
    but the device never downloads from there.
2026-05-23 feat(ota): reboot into minimal downloader mode for the binary fetch
    Even with MQTT shut down, the running firmware leaves only ~18 KB free heap
    once Alexa + device cache + UI router are loaded. BearSSL's TLS handshake
    for the firmware download needs ~17 KB transient, and the SYS task OOM-
    crashes (Exception 29) mid-handshake even from jsDelivr's MFLN-friendly edge.
    Instead of fighting for the last few KB, when a new manifest version is
    detected the updater now stashes the URL+version in a checksum-protected
    RTC RAM slot and reboots. setup() reads (and immediately clears) that slot
    at the very top — before anything but Serial — and routes into a
    stripped-down runDownloaderMode() that ini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
2026-05-23 fix(ota): stream firmware bytes with HTTPClient + Update.h, bigger TLS buffer
    ESPhttpUpdate works on most networks but tacks on 8 x-ESP8266-* request
    headers that look like an embedded-device fingerprint, which appears to
    trigger connection drops at some Cloudflare edges (the WAF/anti-bot side
    of jsDelivr's TLS edge). On top of that the 1 KB TLS receive buffer was
    too small for some MTU-framed response records (~3 KB observed), and
    BearSSL tears down the connection cleanly when it can't fit a record —
    manifesting as HTTPC_ERROR_CONNECTION_LOST right after the GET.
    Replace ESPhttpUpdate with a direct HTTPClient -> Update.h stream that
    mirrors the same HTTPClient setup the (working) manifes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
2026-05-24 fix(ota): carry binary size + md5 in manifest instead of trusting Content-Length
    Some Cloudflare edges drop Content-Length on long-lived TLS streams to
    embedded clients (verified: same URL returns Content-Length to curl but
    not to the device's HTTPClient). Without Content-Length, Update.begin()
    can't size the flash region, so the download aborts before any bytes
    are written.
    Carry the authoritative size + MD5 in the manifest itself. Both are
    populated automatically by release.py (size = stat(), md5 = hashlib of
    the bin file). The device:
    - parses size + md5 from the manifest,
    - threads them through the pending-OTA RTC slot,
    - uses size to bound Update.begin() / the read loop,
    - han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
2026-05-24 fix: initialize Wire for display in downloader mode
2026-05-24 feat: switch OTA back to GitHub Releases with redirect handling
2026-05-24 Revert "feat: switch OTA back to GitHub Releases with redirect handling"
    This reverts commit ef2333637cb7edf1bdd685e1d4b73900a7fe5fee.
2026-05-24 guard OTA check against heap fragmentation
    Add a max_block >= 7 KB gate before manifest fetch so a fragmented heap can't crash the device mid-TLS-handshake. Also instrument each fetch phase with heap samples and report the real PEAK usage in the log to make future threshold tuning data-driven instead of guesswork.
2026-05-24 add gcode
    [WallBase.stl]
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2026-05-24 fix(led): switch v0 and v1 to Adafruit_NeoPixel driver
    NeoRing's FastLED backend on ESP8266 doesn't reliably hold off interrupts
    long enough while WiFi is active, producing visibly choppy animations on
    v0 and v1. v3 was already on the Adafruit_NeoPixel path (which is stricter
    about its critical section) and ran smoothly. Aligning v0 and v1 to the
    same driver fixes the choppiness with no flash-size regression.
    [config.h]
2026-05-24 fix(deps): pin FastLED to 3.9.20; revert v0/v1 to FastLED driver
    Root cause of the v0/v1 LED choppiness shipped in 1.2.1: NeoRing's
    library.json declares its FastLED dependency with no version constraint,
    so PlatformIO's library finder auto-pulls the latest registry release.
    After our .pio/libdeps cache was wiped between 1.2.0 and 1.2.1, the
    build silently moved from a transitively-cached 3.9.x to FastLED 3.10.3
    (Sep 2025), whose namespace and timing reworks make WS2812B animation
    visibly choppy on ESP8266 with WiFi active.
    Pinning FastLED at the project level to 3.9.20 — the last pre-3.10
    release — restores the smooth animation we had through 1.2.0 on both
    the v0 and v1 PCBs (verified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
    [config.h]
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2026-05-25 fix wifi red col
    [SetupOnboardingScreen.h]
2026-05-26 remove temporary Alexa discovery debug logging
    The [Alexa-HTTP] and [Alexa-SSDP] Serial.print blocks were live-debug
    instrumentation added during the discovery investigation. They're noisy
    on the serial port at production scale (Alexa polls /lights every few
    seconds per Echo) and add ~1 KB to flash. Reverting before cutting v1.2.4.
2026-05-26 register Alexa devices as Hue dimmable bulbs, not smart plugs
    On several Echo generations the Alexa app omits the on/off toggle from
    a device's detail page when the device's `type` is "On/Off plug-in unit"
    (real Hue Smart Plug behaviour — Amazon assumes the plug is wired into
    another smart device's UI). Bulbs always render the toggle.
    Switch AlexaConnector to register devices as EspalexaDeviceType::dimmable
    (Hue white lamp, LWB010). This is also upstream Espalexa's default — the
    shape tens of thousands of users ship to Alexa without issue. Our IR
    state callback already maps any value > 0 to ON, so the brightness
    slider Alexa now exposes is harmless: nudging it just re-sends the
    recorded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
2026-05-29 new top cover
    [1.3InchOledPlateTest.stl, Base.stl, Base1of5.stl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]
2026-05-30 3d print update
    [Base.stl, IR Hub V3.f3z, Top Cover New.stl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]
2026-05-30 3d print v100
    [IR Hub V3.f3z, Top Cover.stl]
2026-06-01 update stl
    [Top Cover.stl]
2026-06-01 update 3d print
    [CE3E3V2_Set.3mf]
